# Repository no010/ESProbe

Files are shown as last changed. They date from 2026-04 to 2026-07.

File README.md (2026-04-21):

# ESProbe



ESProbe 是一款基于 **ESP32-C3** 的无线 CMSIS-DAP 调试探针。它通过 WiFi 将 USBIP 协议传输到 PC，使你可以在没有物理 USB 连接的情况下，使用标准调试工具（OpenOCD、Keil、IAR 等）对目标设备进行 SWD 调试。同时内置 UART1 TCP 桥接，方便无线串口调试。

> 本项目固件基于 [wireless-esp8266-dap](https://github.com/windowsair/wireless-esp8266-dap) 移植，适配 ESP-IDF 5.5.x 和 ESP32-C3 硬件平台。

---

## 特性

- **无线 SWD 调试**：通过 WiFi 使用 USBIP 协议，支持 WinUSB 高速传输（512B 包）
- **SPI 硬件加速**：SWD 时钟高达 40MHz（ESP32-C3 SPI2 IOMUX 直接驱动）
- **UART1 TCP 桥接**：独立的 TCP 端口提供无线串口，支持波特率动态切换
- **mDNS 服务**：设备以 `dap.local` 自动发现
- **静态 IP 支持**：默认 `192.168.137.123`，也可使用 DHCP
- **无需 SWO 引脚支持 RTT**：通过标准 SWD 内存读写即可使用 Segger RTT（配合 OpenOCD）
- **低成本硬件**：基于 ESP32-C3-WROOM-02-N4 模组，单面 PCB，立创 EDA 设计

---

## 仓库结构

```
ESProbe/
├── fw/                    # 主固件（ESP-IDF 5.5.x 项目）
│   ├── main/              # 主应用代码
│   ├── components/DAP/    # CMSIS-DAP 核心组件
│   ├── components/USBIP/  # USBIP 协议栈
│   └── build/             # 构建输出
├── hardware/              # 硬件设计文件
│   ├── 3d/                # 外壳 3D 模型
│   ├── *.json             # 立创 EDA 网表
│   └── *.eprj2            # 立创 EDA 项目文件
├── blink/                 # ESP32-C3 LED 示例（验证板子）
├── hello_world/           # ESP32-C3 Hello World 示例
├── bin/                   # OpenOCD 等预编译工具（Windows）
└── README.md
```

---

## 硬件概述

### 主控

- **ESP32-C3-WROOM-02-N4**（乐鑫）
- 160 MHz RISC-V 单核
- 4MB Flash
- 2.4GHz Wi-Fi 802.11 b/g/n + Bluetooth 5 (LE)

### 调试接口（CN1）

10-pin 卧贴连接器（间距 2mm）：

| Pin | 信号 | GPIO | 说明 |
|-----|---|---|---|
| 1 | VCC | — | 3.3V 输出给目标 |
| 2 | GND | — | 地 |
| 3 | UART1 TX  | IO4  | TCP 桥接发送 |
| 4 | UART1 RX  | IO5  | TCP 桥接接收 |
| 5 | SWCLK | IO6  | SPI CLK（IOMUX） |
| 6 | SWDIO | IO7  | SPI MOSI（IOMUX） |
| 7 | nRESET | IO2  | 目标复位（开漏） |
| 8 | nTRST/TDI | IO10 | JTAG 禁用，引脚复用 |
| 9 | GND | — | 地 |
| 10  | GND | — | 地 |

### 状态指示

- **蓝色 LED**（IO0）：WiFi 连接成功后常亮

更多硬件细节参见 [`hardware/README.md`](hardware/README.md)。

---

## 固件概述

### 构建环境

- **ESP-IDF**: v5.5.3
- **目标芯片**: ESP32-C3
- **操作系统**: Windows（Linux/macOS 亦可，需自行配置工具链）

### 快速构建

在 Windows 下使用 ESP-IDF PowerShell：

```powershell
# 打开立创提供的 PowerShell 快捷方式，或手动加载环境
& 'C:\Program Files\PowerShell\7\pwsh.exe' -ExecutionPolicy Bypass -NoProfile -Command "& {. 'C:\Espressif\tools\Microsoft.v5.5.3.PowerShell_profile.ps1'}"

cd fw
idf.py build
idf.py -p COMxx flash monitor
```

详细固件文档参见 [`fw/README.md`](fw/README.md)。

---

## 使用方式

### 1. 连接 WiFi

上电后，设备自动连接 `wifi_configuration.h` 中预配置的 WiFi（默认尝试 `OTA` / `DAP`）。

### 2. 发现设备

- 如果使用静态 IP，直接访问 `192.168.137.123:3240`
- 如果使用 mDNS，通过 `dap.local:3240` 访问

### 3. 在 Windows 上挂载 USBIP

安装 [usbip-win](https://github.com/cezanne/usbip-win) 后：

```powershell
usbip.exe attach -r 192.168.137.123 -b 1-1
```

系统会识别出一个 CMSIS-DAP v2 (WinUSB) 设备，可直接在 Keil、IAR 或 OpenOCD 中使用。

### 4. UART 桥接

使用任意 TCP 客户端连接 `192.168.137.123:1234`：

```powershell
nc 192.168.137.123 1234
```

首次发送的数字字符串会被识别为波特率（如 `115200`），后续数据即为串口透传。

---

## RTT 支持

ESProbe **不需要 SWO 引脚**即可支持 Segger RTT。RTT 通过标准 SWD 内存读写实现：

1. 在目标固件中集成 Segger RTT 代码
2. PC 端启动 OpenOCD，通过 USBIP 连接 ESProbe
3. 使用 OpenOCD RTT 命令读取目标内存缓冲区

```tcl
# OpenOCD 示例
rtt setup 0x20000000 0x1000 "SEGGER RTT"
rtt start
rtt read 0 1024
```

---

## 相关链接

- [ESP32-C3  datasheet](https://documentation.espressif.com/esp32-c3_datasheet_cn.pdf)
- [ESP32-C3 技术参考手册](https://documentation.espressif.com/esp32-c3_technical_reference_manual_cn.pdf)
- [ESP32-C3-WROOM-02-N4 立创商城](https://item.szlcsc.com/datasheet/ESP32-C3-WROOM-02-N4/3281215.html)
- [wireless-esp8266-dap 原项目](https://github.com/windowsair/wireless-esp8266-dap)
- [usbip-win](https://github.com/cezanne/usbip-win)

---

## License

本项目采用 MIT 许可证，详见 [LICENSE](LICENSE)。

固件中的 CMSIS-DAP 代码版权归 ARM Limited 所有，采用 Apache-2.0 许可证。

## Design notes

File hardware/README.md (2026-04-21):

# ESProbe 硬件

ESProbe 采用立创 EDA 设计，单面 PCB，核心为 ESP32-C3-WROOM-02-N4 模组。

## 主要器件

| 位号 | 型号 | 说明 | 供应商 |
|---|---|---|---|
| U1 | ESP32-C3-WROOM-02-N4 | 主控模组，4MB Flash | LCSC C2934560 |
| CN1 | HCZZ0451-8 | 1x8P 卧贴连接器，间距 2mm，调试接口 | LCSC C7433654 |
| USB1 | — | Type-C USB 接口，供电 + UART0 下载 | — |
| D1 | XL-1005UBC | 0402 蓝色 LED，WiFi 状态指示 | LCSC C965795 |
| U3 | — | LDO，3.3V 稳压 | — |
| SW1 | — | 轻触按键，复位/下载 | — |

## 调试连接器（CN1）定义

CN1 为 1x8P（实际引出 10pin，含重复 GND）卧贴连接器，间距 2mm：

```
Pin 1  ── VCC     (3.3V 输出至目标)
Pin 2  ── GND
Pin 3  ── IO4     (UART1 TX)
Pin 4  ── IO5     (UART1 RX)
Pin 5  ── IO6     (SWCLK / FSPICLK)
Pin 6  ── IO7     (SWDIO / FSPID)
Pin 7  ── IO2     (nRESET)
Pin 8  ── IO10    (nTRST / TDI，当前 JTAG 已禁用)
Pin 9  ── GND
Pin 10 ── GND
```

> 注意：Pin 7/8 在物理连接器上为第 7、8 脚，对应原理图中的 IO2 和 IO10。

## 设计文件说明

| 文件 | 格式 | 说明 |
|---|---|---|
| `ESProbe.eprj2` | 立创 EDA 专业版 | 原理图 + PCB 项目文件 |
| `Netlist_Main_2026-04-13.json` | JSON | 立创 EDA 导出的网表 |
| `Netlist_Main_2026-04-13.enet` | 立创网表 | 备用网表格式 |
| `3d/*.stl` | STL | 外壳 3D 打印模型 |
| `ESProbe_backup/` | 立创 EDA | 自动备份历史版本 |

## 硬件特性

- **供电**：5V USB Type-C 输入，板载 LDO 降至 3.3V
- **天线**：ESP32-C3-WROOM-02 板载 PCB 天线，保持 PCB 天线区域净空
- **尺寸**：小型化设计，适配 3D 打印外壳
- **下载**：通过 USB Type-C 直连 UART0，支持一键下载（按住 BOOT + 按 RESET）

## 制板建议

1. 使用立创 EDA 打开 `ESProbe.eprj2`，检查 DRC 后导出 Gerber
2. PCB 天线区域禁止铺铜和放置元件
3. 建议板厚 1.0mm 或 1.2mm，适配 3D 外壳
4. CN1 连接器推荐回流焊，注意卧贴方向与外壳开口对齐

## 外壳

`3d/` 目录包含 STL 格式的上下壳模型，使用 FDM 3D 打印（PLA/PETG 均可）。
安装时先将 PCB 放入下壳，再扣合上壳，CN1 连接器从外壳侧面开口露出。

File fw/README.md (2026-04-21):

# ESProbe 固件

基于 ESP-IDF 5.5.x 的无线 CMSIS-DAP 固件，目标芯片为 ESP32-C3。

## 环境要求

| 项目 | 版本 / 路径 |
|---|---|
| ESP-IDF | v5.5.3 |
| Python | 3.13（由 ESP-IDF 安装程序提供 venv） |
| 芯片目标 | ESP32-C3 |
| 模组 | ESP32-C3-WROOM-02-N4 |

Windows 推荐使用立创/乐鑫提供的 PowerShell 环境快捷方式启动：

```powershell
"C:\Program Files\PowerShell\7\pwsh.exe" -ExecutionPolicy Bypass -NoProfile -Command "& {. 'C:\Espressif\tools\Microsoft.v5.5.3.PowerShell_profile.ps1'}"
```

## 项目结构

```
fw/
├── CMakeLists.txt              # 项目根 CMake，IDF_TARGET=esp32c3
├── sdkconfig.defaults          # 默认 Kconfig（WiFi 缓冲区、TCP 参数等）
├── main/                       # 主应用组件
│   ├── main.c                  # app_main：初始化 WiFi、mDNS、DAP、TCP Server
│   ├── wifi_handle.c           # WiFi STA 模式、静态 IP、事件处理
│   ├── tcp_server.c            # BSD socket TCP 服务器（端口 3240）
│   ├── usbip_server.c          # USBIP Stage1/Stage2 协议处理
│   ├── DAP_handle.c            # DAP 命令环形缓冲 + 工作线程
│   ├── uart_bridge.c           # UART1 <-> TCP 桥接（端口 1234）
│   ├── timer.c                 # DAP 时间戳计数器（ESP32-C3 上 stubbed）
│   ├── dap_configuration.h     # WinUSB、包大小、强制复位等开关
│   └── wifi_configuration.h    # WiFi SSID、静态 IP、功能开关
├── components/
│   ├── DAP/                    # CMSIS-DAP v2.1.0 核心
│   │   ├── config/DAP_config.h # 引脚映射、时钟、能力位
│   │   ├── source/DAP.c        # DAP 命令解析器
│   │   ├── source/SW_DP.c      # SWD 传输（GPIO bit-bang + SPI 高速）
│   │   ├── source/spi_switch.c # SPI2 初始化/去初始化，IOMUX 切换
│   │   ├── source/spi_op.c     # SPI 加速的 SWD 时序操作
│   │   └── source/...          # JTAG_DP.c, SWO.c, swd_host.c 等
│   └── USBIP/                  # USBIP 协议栈 + 描述符
│       ├── usb_descriptor.c    # USB 设备/配置/接口描述符
│       ├── MSOS20_descriptor.c # Microsoft OS 2.0 描述符（WinUSB 免驱）
│       └── usb_handle.c        # USB 控制请求处理
└── managed_components/
    └── espressif__mdns/        # idf.py add-dependency 引入
```

## 构建步骤

```bash
cd fw

# 完整重新构建（推荐首次或修改 sdkconfig 后）
idf.py fullclean
idf.py build

# 烧录并监控串口
idf.py -p COMxx flash monitor
```

烧录偏移：
- Bootloader: `0x0`
- Partition Table: `0x8000`
- App: `0x10000`

## 关键配置

### WiFi 凭证

编辑 `main/wifi_configuration.h`：

```c
static struct {
    const char *ssid;
    const char *password;
} wifi_list[] = {
    {.ssid = "YOUR_SSID", .password = "YOUR_PASSWORD"},
};
```

支持多 AP 轮询，断连后自动切换下一个。

### 静态 IP

同样在 `wifi_configuration.h` 中：

```c
#define USE_STATIC_IP 1
#define DAP_IP_ADDRESS 192, 168, 137, 123
#define DAP_IP_GATEWAY 192, 168, 137, 1
#define DAP_IP_NETMASK 255, 255, 255, 0
```

### 功能开关

| 宏 | 位置 | 默认 | 说明 |
|----|---|---|---|
| `USE_WINUSB` | `dap_configuration.h` | 1 | WinUSB bulk 模式（512B），关闭则回退 HID |
| `USE_SPI_SIO` | `dap_configuration.h` | 1 | MOSI 单线回环，无需物理短接 MISO |
| `USE_UART_BRIDGE` | `wifi_configuration.h` | 1 | UART1 TCP 桥接 |
| `UART_BRIDGE_PORT` | `wifi_configuration.h` | 1234 | 串口桥接 TCP 端口 |
| `USE_MDNS` | `wifi_configuration.h` | 1 | mDNS 服务 `dap.local` |
| `DAP_JTAG` | `DAP_config.h` | 0 | JTAG 已禁用，仅保留 SWD |

## 引脚映射（ESP32-C3）

| 功能 | GPIO | 备注 |
|---|---|---|
| SWCLK | IO6 | FSPICLK，IOMUX 直连，SPI 加速 |
| SWDIO | IO7 | FSPID，IOMUX 直连，SPI 加速 |
| UART1 TX | IO4 | TCP 桥接发送 |
| UART1 RX | IO5 | TCP 桥接接收 |
| nRESET | IO2 | 目标复位，开漏输出 |
| LED | IO0 | WiFi 状态指示灯 |

## 架构说明

### 任务模型

| 任务 | 优先级 | 核心 | 职责 |
|---|---|---|---|
| `tcp_server` | 14 | 0 | 监听 3240 端口，USBIP Stage1/Stage2 协议 |
| `DAP_Task` | 10 | 0 | 从 ringbuffer 取出 DAP 命令并执行 |
| `uart_server` | 2 | — | UART1 <-> TCP 事件处理 |

### USBIP 数据流

1. 主机发送 `OP_REQ_DEVLIST` / `OP_REQ_IMPORT` → 固件回复设备描述符
2. 进入 URB 循环：
   - **EP1 OUT** → DAP 命令 → `dap_dataIN_handle` → 通知 `DAP_Task`
   - **EP1 IN** ← DAP 响应 ← `dap_dataOUT_handle` ← `fast_reply()`
   - **EP0** → USB 控制请求（WinUSB 描述符等）

### SPI 加速

当调试器请求时钟 ≥ 10MHz 时，`DAP_SWJ_Clock()` 调用 `DAP_SPI_Init()`，将 IO6/IO7 切换到 SPI2 IOMUX 功能，以 40MHz APB 时钟硬件驱动 SWD 时序。低速或协议切换时自动回退到 GPIO bit-bang。

## 已知限制

- **SPI 加速未经验证**：`spi_op.c` 在 ESP32-C3 上的时序尚未用逻辑分析仪验证，如调试不稳定可强制使用 GPIO 模式（时钟 < 10MHz）
- **Timer stubbed**：`get_timer_count()` 在 ESP32-C3 上返回 0，DAP 时间戳功能不可用
- **OTA / WebSocket / KCP 未移植**：MVP 版本仅保留无线 DAP + UART 桥接

## 调试串口输出

ESP32-C3 的 UART0（USB-Serial-JTAG）用于固件日志输出，默认波特率 115200。在 `idf.py monitor` 中可直接查看。

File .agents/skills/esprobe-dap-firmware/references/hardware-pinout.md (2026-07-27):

# Hardware Pinout Reference

## ESProbe ESP32-C3 Target Pin Mapping

All debug signals route to the 10-pin ARM Cortex Debug Connector (CN1) unless noted.

| CN1 Pin | Signal | GPIO | IOMUX Function | Direction | Drive | Note |
|---|---|---|---|---|---|---|
| 1 | VCC | — | — | Power out | — | 3.3V to target |
| 2 | SWDIO | 7 | FSPID (FUNC_MTDO_FSPID) | I/O | 5mA | SPI MOSI, SIO mode |
| 3 | UART1 TX  | 4 | GPIO | Output | — | TCP bridge TX |
| 4 | UART1 RX  | 5 | GPIO | Input | — | TCP bridge RX |
| 5 | SWCLK | 6 | FSPICLK (FUNC_MTCK_FSPICLK) | Output | 5mA | SPI CLK |
| 6 | GND | — | — | — | — | |
| 7 | nRESET | 2 | GPIO | OD out | — | Active low, pull-up |
| 8 | nTRST/TDI | 10 | GPIO | OD out | — | JTAG disabled, reused |
| 9 | NC | — | — | — | — | |
| 10 | GND | — | — | — | — | |

## LED

| Function | GPIO | Active | Control Location |
|---|---|---|---|
| WiFi status | 0 | High | `wifi_handle.c` event handler |

## Cross-SoC Pin Comparison

| Signal | ESP8266 | ESP32 | ESP32-C3 | ESP32-S3 |
|---|---|---|---|---|
| SWCLK | 14 | 14 | 6 | 12 |
| SWDIO | 12/13 | 12/13 | 7 | 11 |
| UART1 TX | — | 23 | 4 | — |
| UART1 RX | — | 22 | 5 | — |
| nRESET | 5 | 26 | 2 | 13 |
| nTRST | 0 | 25 | 10 | 14 |
| LED | 15 | 27 | 0 | 4 |

## ESP32-C3 IOMUX Details

When using SPI acceleration, pins must be routed through IOMUX (not GPIO matrix) for full-speed timing:

- **GPIO6 (SWCLK)**: `FUNC_MTCK_FSPICLK` — IO_MUX direct connect for SPI2 clock
- **GPIO7 (SWDIO)**: `FUNC_MTDO_FSPID` — IO_MUX direct connect for SPI2 MOSI

In GPIO fallback mode, pins are switched back via `PIN_FUNC_SELECT(IO_MUX_GPIOx_REG, FUNC_MTCK_GPIO6)` (or equivalent GPIO function).

## Drive Strength

`DAP_SETUP()` sets drive capability to `GPIO_DRIVE_CAP_0` (5mA) for SWCLK and SWDIO on ESP32-C3/S3. Increase if signal integrity is poor at higher frequencies, but watch for overshoot on long traces.

## Adding a New Board Variant

If creating a derivative board with different pins:

1. Update `PIN_*` macros in `components/DAP/config/DAP_config.h`.
2. Ensure the new SWCLK/SWDIO pins support IOMUX SPI2 if SPI acceleration is desired.
3. Update `PORT_JTAG_SETUP()` if the new TDO pin requires special handling (e.g., RTC pin on ESP8266).
4. Verify `DAP_SPI_Init()` uses correct `IO_MUX_GPIOx_REG` and `FUNC_*` constants.

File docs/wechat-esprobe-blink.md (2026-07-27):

# 不要小看 Blink：ESProbe 的第一颗“心跳灯”

做一块调试器，最激动人心的时刻往往不是第一次跑通 OpenOCD，而是板子上那颗小小的 LED 按预期闪起来。

ESProbe 是一个基于 ESP32-C3 的无线 CMSIS-DAP 调试探针。它最终要通过 WiFi 把 USBIP 设备暴露给 PC，让 OpenOCD、Keil、IAR 等工具像使用普通 CMSIS-DAP 一样进行 SWD 调试。但在 USBIP、WinUSB、SWD 时序、UART TCP 桥接这些复杂模块之前，最应该先做的事情其实很朴素：

让板载 LED 闪起来。

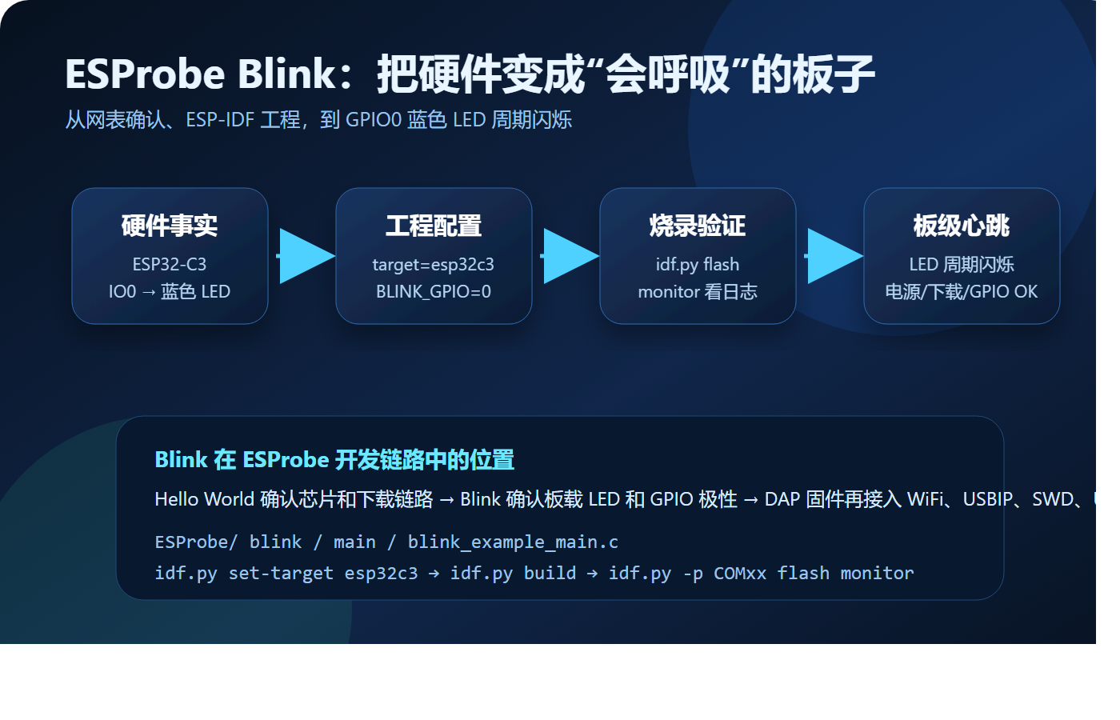
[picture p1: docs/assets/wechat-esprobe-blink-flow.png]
ESProbe Blink 验证流程


## 为什么 Blink 值得单独写一篇

Blink 不是“入门玩具”，而是硬件 Bring-up 的第一道闸门。

对于 ESProbe 这样的板子，Blink 一次性验证了几件基础事实：

| 验证项 | 意义 |
| --- | --- |
| ESP32-C3 能启动 | 电源、Flash、启动配置基本正常 |
| ESP-IDF target 正确 | 工程确实按 `esp32c3` 编译 |
| Type-C 下载链路可用 | 后续固件迭代不会卡在烧录阶段 |
| GPIO 输出可控 | 板载 LED 网络和固件配置对齐 |
| 日志能正常输出 | `idf.py monitor` 能用于后续调试 |

这些事情看起来简单，但如果跳过它们，后面调 WiFi、USBIP 或 SWD 时，一旦出现异常，就很难判断问题来自协议、驱动、网络，还是最底层的硬件没有起来。

## ESProbe 的 LED 接在哪里

ESProbe 的主控是 ESP32-C3-WROOM-02-N4，板载蓝色 LED 连接在 GPIO0 上。这个设计在主固件里也被用作 WiFi 状态指示灯。

需要特别注意的是，很多板载 LED 并不是“GPIO 输出高电平点亮”。ESProbe 的 LED 由 3.3V 侧供电，GPIO0 下拉导通，因此它更接近低电平点亮的连接方式。

在 Blink 示例阶段，我们关心的不是效果多炫，而是先确认固件里的 `BLINK_GPIO` 与硬件事实一致。

## blink 示例项目结构

仓库里的 Blink 工程位于：

```text
blink/
├── CMakeLists.txt
├── sdkconfig.defaults
├── main/
│   ├── blink_example_main.c
│   ├── CMakeLists.txt
│   ├── Kconfig.projbuild
│   └── idf_component.yml
└── managed_components/
```

它来自 ESP-IDF 的标准 blink 示例，但保留在 ESProbe 仓库中后，就不只是示例代码，而是板级验证用例。

顶层 `CMakeLists.txt` 使用 ESP-IDF 标准工程结构，并开启 `MINIMAL_BUILD`：

```cmake
include($ENV{IDF_PATH}/tools/cmake/project.cmake)
idf_build_set_property(MINIMAL_BUILD ON)
project(blink)
```

这让工程只编译必要组件，适合做快速验证。

## 配置 Blink GPIO

Blink 示例通过 Kconfig 暴露了两个关键配置：

```text
CONFIG_BLINK_GPIO
CONFIG_BLINK_PERIOD
```

在 `main/Kconfig.projbuild` 中可以看到默认 GPIO 和闪烁周期配置。对 ESProbe 来说，重点是把 LED 引脚配置到 GPIO0：

```text
BLINK_GPIO=0
BLINK_PERIOD=1000
```

如果 LED 闪烁状态和日志里的 ON/OFF 语义相反，不要急着怀疑芯片坏了。先回到硬件连接，确认 LED 是否为低电平点亮。对嵌入式开发来说，“灯亮了”只是第一步，“灯为什么这样亮”才是真正有价值的结论。

## 主程序做了什么

`blink/main/blink_example_main.c` 的逻辑很清楚：

1. 根据配置选择普通 GPIO LED 或地址灯带。
2. 初始化 GPIO 输出。
3. 在 `while (1)` 中周期性切换状态。
4. 通过 `ESP_LOGI` 打印当前动作。

核心循环可以概括为：

```c
while (1) {
    ESP_LOGI(TAG, "Turning the LED %s!", s_led_state == true ? "ON" : "OFF");
    blink_led();
    s_led_state = !s_led_state;
    vTaskDelay(CONFIG_BLINK_PERIOD / portTICK_PERIOD_MS);
}
```

这段代码的价值不在算法，而在“每一次 GPIO 翻转都有日志对应”。如果串口日志在跑，但 LED 不闪，优先查 GPIO 和硬件连接；如果 LED 闪但没有日志，优先查 monitor、串口号或 USB Serial/JTAG。

## 构建和烧录

在 ESP-IDF 5.5.x PowerShell 环境中执行：

```powershell
cd <你的项目目录>\blink
idf.py set-target esp32c3
idf.py build
idf.py -p COMxx flash monitor
```

正常情况下，日志会周期性出现：

```text
I (xxxx) example: Turning the LED ON!
I (xxxx) example: Turning the LED OFF!
```

同时，ESProbe 板载蓝色 LED 按设定周期闪烁。

## Blink 和 ESProbe 主固件的关系

ESProbe 主固件要做的事情远比 Blink 复杂：

```text
WiFi STA 连接
mDNS 设备发现
TCP 3240 USBIP 服务
WinUSB / CMSIS-DAP v2 描述符
DAP 命令环形缓冲
SWD GPIO / SPI 时序
UART1 TCP 桥接
```

这些模块任何一个出问题，表面现象都可能只是“PC 端连不上”或“调试器不响应”。因此 Blink 的作用就是先给开发者一个底座：板子能启动、能下载、能输出、能控制 GPIO。

有了这颗“心跳灯”，后续调试才有方向感。

## 结语

Blink 是 ESProbe 的第一个可见反馈，也是从硬件设计走向固件系统的分界线。

当蓝色 LED 开始闪烁时，它证明的不只是一个 GPIO，而是整条基础开发链路已经闭合：

```text
硬件网表 → ESP-IDF 工程 → 编译 → 烧录 → 日志 → GPIO 输出
```

下一步，才值得把 WiFi、USBIP 和 CMSIS-DAP 一层层接上去。

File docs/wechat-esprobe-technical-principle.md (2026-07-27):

# ESProbe 技术原理：IDE 以为连着 USB，其实中间跑了一段 WiFi

ESProbe 的目标很直接：把一只基于 ESP32-C3 的小板子变成无线 CMSIS-DAP 调试探针。

但它真正有意思的地方，不是“ESP32-C3 会连 WiFi”，而是它选择了一条非常工程化的路径：

```text
不改 IDE，不改 OpenOCD，不发明私有调试协议。
让电脑仍然看到一个标准 CMSIS-DAP USB 设备。
只是这个 USB 设备，被 USB/IP 搬到了 WiFi 另一端。
```

这篇文章重点拆解 ESProbe 的技术原理，尤其是网络链路，以及它和 IDE、OpenOCD、pyOCD 这些工具之间的架构关系。

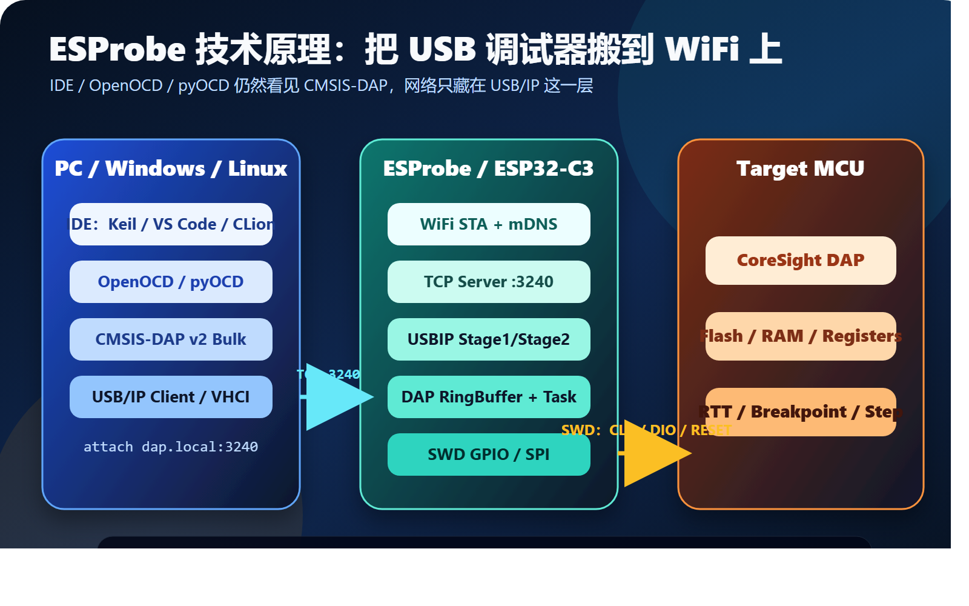
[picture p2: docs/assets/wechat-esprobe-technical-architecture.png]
ESProbe 技术架构图


## 先看一句话架构

ESProbe 可以理解为三层桥接：

| 层级 | ESProbe 做的事 | 上层看到什么 |
| --- | --- | --- |
| 网络层 | ESP32-C3 连接 WiFi，监听 TCP 3240 | 一个 USB/IP 远端设备 |
| USB 层 | 用 USB/IP 模拟 USB 枚举和 URB 传输 | 一个 CMSIS-DAP v2 / WinUSB 设备 |
| 调试层 | 把 DAP 命令转换成 SWD 引脚时序 | 一只普通 CMSIS-DAP 探针 |

也就是说，ESProbe 不是让 OpenOCD 直接通过 TCP 控制 SWD 引脚，而是先让操作系统通过 USB/IP“挂载”一个虚拟 USB 设备。之后 OpenOCD、pyOCD 或 IDE 只需要按普通 CMSIS-DAP 设备来使用它。

## PC 端：IDE 并不知道 WiFi 的存在

在 PC 端，用户通常会使用三类工具：

```text
IDE：Keil、IAR、VS Code、CLion、Eclipse
调试服务：OpenOCD、pyOCD、probe-rs、厂商 GDB Server
底层探针协议：CMSIS-DAP、J-Link、ST-Link、FTDI 等
```

ESProbe 选择 CMSIS-DAP，是因为它是 Arm 生态中比较通用的调试探针协议。Arm 官方对 CMSIS-DAP 的定位，就是在主机调试软件和目标芯片 CoreSight Debug Access Port 之间提供标准化访问。

对 IDE 来说，真正交互的对象往往不是 ESProbe 本身，而是 OpenOCD 或 pyOCD：

```text
IDE / GDB 前端
    ↓
OpenOCD / pyOCD
    ↓
CMSIS-DAP 适配层
    ↓
操作系统中的 USB 设备
```

只要操作系统里出现了一个可用的 CMSIS-DAP v2 设备，上层工具链就可以沿用原来的工作方式。

这正是 ESProbe 的设计重点：网络化发生在 USB/IP 层，而不是强迫每个 IDE 都支持一种新的“WiFi DAP 协议”。

## 网络层：WiFi STA、静态 IP 和 mDNS

ESProbe 固件启动后，首先初始化 NVS、UART 桥、WiFi、DAP 核心和定时器。

在 `app_main()` 中，主要任务包括：

```text
wifi_init()
DAP_Setup()
timer_init()
mdns_setup()
tcp_server_task
DAP_Thread
uart_bridge_task
```

网络部分的核心在 `wifi_handle.c`：

- 使用 ESP32-C3 的 WiFi STA 模式连接路由器或热点。
- 支持多个 SSID 轮询，断线后自动切换。
- 关闭 WiFi 省电模式，降低交互延迟。
- 获取 IP 后点亮 WiFi 状态 LED。
- 默认支持 mDNS，主机名为 `dap.local`。

固件当前的 USB/IP 端口是：

```text
TCP 3240
```

这不是随便选的端口。USB/IP 生态中常用的服务端口就是 3240，因此 Windows 或 Linux 侧的 USB/IP 客户端更容易按标准方式连接。

对用户来说，典型连接目标是：

```text
192.168.137.123:3240
dap.local:3240
```

## TCP Server：先判断你说的是哪种协议

ESProbe 的 `tcp_server_task` 会创建 BSD socket，绑定端口，监听连接。

连接建立后，它先读取 4 字节 header，然后判断对端发来的是什么协议：

| Header 类型 | 含义 | 后续处理 |
| --- | --- | --- |
| USB/IP `OP_REQ_DEVLIST` | 主机请求设备列表 | 返回一个虚拟 USB 设备 |
| USB/IP `OP_REQ_IMPORT` | 主机请求导入设备 | 进入 URB 传输阶段 |
| elaphureLink 标识 | 兼容旧协议入口 | 进入 elaphureLink 处理 |
| 其他 | 未知协议 | 关闭连接 |

ESProbe 主线使用的是 USB/IP。连接断开时，固件会关闭 socket，并通知 DAP 任务重置状态，避免上一次连接残留的 DAP 响应污染下一次会话。

这点很重要。USB 调试链路是有时序和请求-响应关系的，如果网络断开后 ringbuffer 中还有旧响应，下一次 attach 可能会读到错包，导致主机端驱动或调试工具状态错乱。

## USB/IP：把 USB 设备“搬运”到网络上

USB/IP 可以分成两个阶段理解。

第一阶段是发现和导入：

```text
OP_REQ_DEVLIST  →  你有哪些 USB 设备？
OP_REQ_IMPORT   →  我要挂载 busid=1-1 的设备。
```

ESProbe 固件会返回一个设备列表，其中只有一个虚拟设备。它的 busid 是 `1-1`，设备描述符来自固件中的 USB descriptor。

第二阶段是 URB 传输。主机不再问“你有哪些设备”，而是开始像操作 USB 设备一样提交 URB：

| USB/IP Stage2 请求 | ESProbe 行为 |
| --- | --- |
| EP0 控制请求 | 返回设备、配置、字符串、Microsoft OS 2.0 描述符 |
| EP1 OUT | 接收 CMSIS-DAP 命令包 |
| EP1 IN | 返回 CMSIS-DAP 响应包 |
| UNLINK | 取消挂起 URB，清理等待队列 |

这就是 ESProbe 最关键的伪装：它没有真正的 USB 外设控制器连接到 PC，但它通过 USB/IP 回复了足够完整的 USB 行为，让 PC 端认为自己挂载了一个远端 USB 设备。

## 为什么是 CMSIS-DAP v2 / WinUSB

CMSIS-DAP 有两个常见 USB 传输形态：

| 版本 | USB 类型 | 特点 |
| --- | --- | --- |
| CMSIS-DAP v1 | HID | 免驱友好，但包和吞吐受限 |
| CMSIS-DAP v2 | Vendor-specific bulk / WinUSB | 更适合高速传输，pyOCD 和 OpenOCD 都支持 |

ESProbe 默认启用 `USE_WINUSB=1`，并把 DAP packet size 设置为 512 字节。固件还提供 Microsoft OS 2.0 描述符，目的是让 Windows 更容易把接口绑定到 WinUSB。

这对 OpenOCD 和 pyOCD 都很关键。它们并不需要知道 ESProbe 背后是 ESP32-C3，也不需要知道中间是 WiFi。它们只要能通过系统 USB 栈访问到 CMSIS-DAP bulk endpoint，就能发起 DAP 命令。

## DAP 命令如何穿过 ESProbe

一次典型的读内存、写寄存器或下载固件，会被拆成很多 CMSIS-DAP 命令包。

在 ESProbe 内部，数据路径大致是：

```text
USB/IP EP1 OUT
    ↓
handle_dap_data_request()
    ↓
dap_dataIN_handle ringbuffer
    ↓
xTaskNotifyGive(DAP_Task)
    ↓
DAP_ProcessCommand()
    ↓
dap_dataOUT_handle ringbuffer
    ↓
USB/IP EP1 IN fast_reply()
```

这里有两个任务在配合：

| 任务 | 优先级 | 职责 |
| --- | --- | --- |
| `tcp_server_task` | 14 | 处理 TCP、USB/IP、URB 收发 |
| `DAP_Task` | 10 | 执行 CMSIS-DAP 命令，驱动 SWD |

这种设计把网络收发和 DAP 执行拆开：TCP 任务负责尽快接包和回包，DAP 任务负责相对耗时的 SWD 事务。

## 从 CMSIS-DAP 到 SWD 引脚

CMSIS-DAP 命令进入 `DAP_ProcessCommand()` 后，会落到 CMSIS-DAP core 中的具体命令处理逻辑。

对于 ESProbe 当前目标，最重要的是 SWD：

```text
DAP 命令
    ↓
SW_DP.c
    ↓
GPIO bit-bang 或 SPI 加速
    ↓
GPIO6: SWCLK
GPIO7: SWDIO
GPIO2: nRESET
```

ESProbe 固件中 JTAG 当前是关闭的，主路径是 SWD。低速或协议切换阶段使用 GPIO bit-bang；高频数据传输阶段可以尝试通过 ESP32-C3 的 SPI 外设加速 SWD 波形。

从目标芯片角度看，它并不知道调试请求来自 WiFi。它只看到标准的 SWD 时序：SWCLK、SWDIO、nRESET。

## OpenOCD 在这条链路里的位置

OpenOCD 的角色是“调试服务器”和“适配器驱动集合”。

在 ESProbe 场景里，它通常位于 IDE/GDB 和 CMSIS-DAP 设备之间：

```text
GDB / IDE
    ↓ remote target
OpenOCD
    ↓ cmsis-dap adapter
ESProbe 虚拟 USB 设备
    ↓ USB/IP over WiFi
ESProbe 固件
    ↓ SWD
Target MCU
```

OpenOCD 负责理解目标芯片、Flash 算法、断点、寄存器、GDB remote protocol 等；ESProbe 负责把 CMSIS-DAP 命令变成 SWD 电气信号。

这意味着 ESProbe 不需要内置每一种 MCU 的烧录算法。目标芯片差异主要交给 OpenOCD 配置文件处理。

一个典型 OpenOCD 配置思路是：

```tcl
adapter driver cmsis-dap
transport select swd
adapter speed 4000
source [find target/xxx.cfg]
```

如果 Windows 已经通过 USB/IP 把 ESProbe attach 成 CMSIS-DAP v2 设备，OpenOCD 就按普通 CMSIS-DAP 探针使用它。

## pyOCD 在这条链路里的位置

pyOCD 更偏 Python 生态，常用于 Cortex-M 的烧录、调试、自动化测试和脚本化访问。

pyOCD 官方文档把 debug probe 定义为 pyOCD 和 target 之间的接口，并通过 probe driver 插件支持多种探针，其中包括 `cmsisdap`。它也明确区分了 CMSIS-DAP v1 HID 和 v2 bulk，通常会优先使用 v2。

在 ESProbe 场景里，pyOCD 的链路是：

```text
pyocd gdbserver / pyocd flash / Python API
    ↓
cmsisdap probe plugin
    ↓
操作系统 USB 栈中的 CMSIS-DAP v2 设备
    ↓
USB/IP client
    ↓
ESProbe over WiFi
    ↓
SWD target
```

pyOCD 的优势在于脚本化和自动化。如果你希望在 CI、产测脚本或 Python 工具里批量烧录、读取寄存器、做基础连通性测试，pyOCD 会比完整 IDE 更轻量。

## IDE、OpenOCD、pyOCD 和 ESProbe 的边界

可以把它们的职责边界这样记：

| 组件 | 负责什么 | 不负责什么 |
| --- | --- | --- |
| IDE | 用户界面、工程、断点操作 | 不直接处理 WiFi/USBIP |
| OpenOCD | GDB server、目标芯片、Flash、适配器驱动 | 不关心 ESProbe 内部 WiFi 实现 |
| pyOCD | Python 化调试/烧录、CMSIS-DAP probe 访问 | 不负责 ESProbe 的 TCP server |
| USB/IP client | 把远端 USB 设备挂到本机 USB 栈 | 不理解 CMSIS-DAP 语义 |
| ESProbe 固件 | USB/IP server、CMSIS-DAP core、SWD 引脚 | 不内置 IDE 和目标芯片工程逻辑 |

这个分工让系统具有可替换性：

- IDE 可以换，只要它能通过 GDB server 或 CMSIS-DAP 工作。
- OpenOCD 可以换成 pyOCD，只要目标芯片支持。
- Windows USB/IP 客户端可以换，只要它能正确 attach ESProbe。
- ESProbe 固件可以迭代网络和 SWD 性能，而不破坏上层工具链。

## 网络化带来的挑战

无线调试不是把 USB 线剪掉这么简单。ESProbe 需要面对几个网络化后的问题。

第一是时延。USB 调试器原本在本机 USB 总线上，往返延迟很低；WiFi 加 TCP 后，每个请求-响应都会多一层网络时延。因此固件中关闭 WiFi 省电、启用 `TCP_NODELAY`，都是为了减少交互延迟。

第二是队列同步。主机可能预先提交 IN URB，也可能在超时后发送 UNLINK。ESProbe 需要保存待回复的 IN header，并在 DAP 响应准备好后匹配回去；连接断开或取消时还要清理状态。

第三是包大小和吞吐。WinUSB bulk 512 字节包比 HID 更适合传输 DAP 命令，但 WiFi 仍然不是 USB 高速总线。因此 ESProbe 把 USB 速度上报为 Full Speed，并在固件里围绕 512 字节 DAP packet 做处理。

第四是发现和连接体验。静态 IP 简单可靠，mDNS 的 `dap.local` 更方便用户记忆。实际产品化时，还可以继续做配网、设备列表、Web 配置页等体验优化。

## 为什么不直接做一个 OpenOCD TCP Adapter

理论上，ESProbe 可以设计成“OpenOCD 直接连 ESP32-C3 的 TCP 服务，然后发送私有命令”。这样固件可能更简单。

但代价也很明显：

```text
每个工具都要适配私有协议
Windows IDE 很难直接复用
pyOCD 未必能原生支持
用户需要理解更多网络配置
生态兼容性变差
```

USB/IP 的好处是把网络层藏在操作系统 USB 栈下面。只要 attach 成功，后面的软件路径就回到了成熟的 CMSIS-DAP 生态。

ESProbe 的工程取舍是：底层实现更复杂一点，换取上层工具链更少改动。

## 总结

ESProbe 的核心不是“ESP32-C3 + WiFi + SWD”这几个关键词的简单相加，而是一套清晰的分层架构：

```text
IDE / GDB
    ↓
OpenOCD / pyOCD
    ↓
CMSIS-DAP v2
    ↓
USB/IP
    ↓
WiFi TCP 3240
    ↓
ESP32-C3 DAP 固件
    ↓
SWD
    ↓
Target MCU
```

它让网络调试尽量保持“上层无感”：IDE 仍然使用 OpenOCD 或 pyOCD，OpenOCD/pyOCD 仍然使用 CMSIS-DAP，只有 USB 设备本身被 USB/IP 延伸到了 WiFi 另一端。

这就是 ESProbe 最有价值的技术路线：用标准协议做无线化，而不是用私有协议重造整个调试生态。

## 参考资料

- Arm CMSIS-DAP: https://arm-software.github.io/CMSIS_6/main/DAP/index.html
- OpenOCD Debug Adapter Configuration: https://openocd.org/doc-release/html/Debug-Adapter-Configuration.html
- pyOCD Debug Probes: https://pyocd.io/docs/debug_probes.html
- ESProbe 固件：`fw/main/tcp_server.c`、`fw/main/usbip_server.c`、`fw/main/DAP_handle.c`

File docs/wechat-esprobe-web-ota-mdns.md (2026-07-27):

# 给无线调试器装上"大脑"：ESProbe 的一次固件进化

上一篇我们聊了 ESProbe 为什么在 Keil 下用 USBIP 会不稳定，以及 elaphureLink 这条更短的路。这一篇换个视角——不谈协议对抗，谈**产品化**。

一个能跑通 SWD 的 ESP32-C3 只是"能用"。要变成"好用"，还差几样东西：改 WiFi 得重新烧录、升级固件得插线、局域网里两个探针分不清谁是谁、板上那颗灯永远只会"亮"或"不亮"。

这次我们一口气补上了五个特性，让 ESProbe 从"一块能调试的板子"变成"一台有配置界面、能自我升级、可被发现的设备"。

---

## 先看一张改动全景图

```mermaid
flowchart TB
    subgraph 上电启动
    A[app_main] --> B[LED 状态机启动]
    B --> C[USB 序列号<br/>从 MAC 生成]
    C --> D[WiFi 连接]
    D --> E{连上了?}
    E -->|是| F[STA 模式]
    E -->|重试 N 次失败| G[AP fallback 模式]
    end

    F --> H[mDNS 广播<br/>_dap._tcp + _http._tcp]
    G --> H
    H --> I[Web 服务器 :80]
    I --> J[配置门户 /]
    I --> K[状态接口 /status]
    I --> L[OTA 升级 /ota]
```

这五个特性不是孤立的功能点，而是围绕一个核心问题展开：**如何让一台没有屏幕、没有按键阵列的嵌入式设备，具备完整的配置与维护能力？**

---

## 特性一：Web 配置门户——让改 WiFi 不再需要烧录

### 问题的根源

ESProbe 的 WiFi 凭证一直硬编码在 `wifi_configuration.h` 里，改个网络就得重新编译、重新烧录。这在开发阶段能忍，但作为产品是灾难。

上一轮我们已经加了 **NVS 凭证存储**和 **AP fallback 模式**（连不上就自己开热点），但当时留了个尾巴——存储层的 `wifi_config_store_save()` 写好了，却没有任何界面去调用它。用代码评审的话说，这是一段**死代码**。

这一轮就是来补上这最后一块拼图的。

### 方案：AP 模式下的配置网页

当 ESProbe 连不上预设 WiFi、进入 AP fallback 模式（SSID 形如 `ESProbe-A1B2`）后，用手机或电脑连上它，浏览器打开 `192.168.4.1`，就能看到一个配置页：

```
┌─────────────────────────┐
│  ESProbe Config         │
├─────────────────────────┤
│  WiFi                   │
│  [SSID____________]     │
│  [Password________]     │
│  [ Save & Reboot ]      │
├─────────────────────────┤
│  Status  {json...}      │
├─────────────────────────┤
│  Firmware Update (OTA)  │
│  [选择文件] [Upload]     │
└─────────────────────────┘
```

填入新的 SSID/密码，点击保存，固件把凭证写入 NVS 后自动重启，用新配置重连。整个过程不需要电脑上装任何工具，不需要串口，更不需要重新编译。

### 技术细节：为什么用 esp_http_server 而不是自己撸 socket

ESProbe 的 TCP 3240（USBIP/elaphureLink）和 1234（UART 桥）都是手写的 BSD socket 循环。但配置门户我们直接用了 ESP-IDF 自带的 `esp_http_server`：

| 维度 | 手写 socket | esp_http_server |
| --- | --- | --- |
| HTTP 解析 | 自己处理 method/header/body | 内置 |
| 路由 | 自己 if-else | `httpd_register_uri_handler` |
| 分块接收 | 自己管理缓冲 | `httpd_req_recv` |
| 维护成本 | 高 | 低 |

调试器的数据通道追求极致低延迟，值得手写优化；但配置门户是低频操作，稳定和省心比性能重要。**在合适的地方用合适的抽象**，这是工程判断。

表单提交用的是标准 `application/x-www-form-urlencoded`，固件里用 `httpd_query_key_value` 提取字段，再做一次 URL 解码（处理 `%XX` 和 `+`）。这样即使 WiFi 密码里有空格、`&`、中文，也能正确还原。

---

## 特性二：无线 OTA——升级固件不用再插线

### 从"单分区"到"双分区"

要支持在线升级，第一步是改分区表。ESProbe 原本用的是 ESP-IDF 默认的单 App 分区（`singleapp`）——整块 Flash 只有一个固件槽。想 OTA，就必须有第二个槽：写新固件的时候，旧固件还在运行。

我们切换到了 ESP-IDF 内置的 `two_ota` 分区表：

```mermaid
flowchart LR
    subgraph 4MB Flash
    N[nvs] --> O[otadata]
    O --> P[ota_0<br/>1MB app]
    P --> Q[ota_1<br/>1MB app]
    end
```

`otadata` 记录当前该从哪个槽启动。升级时写入空闲槽，成功后把启动指针指向它，重启即生效。如果新固件启动失败，还能回滚——这是双分区最大的价值：**升级失败不变砖**。

> 编译后实测：固件 918KB，单个 app 槽 1MB，剩余 10% 空间。刚好够用，也说明该给未来的功能留意体积了。

### 推还是拉？我们选了"推"

OTA 有两种典型模式：

- **拉（pull）**：设备主动去某个 URL 下载固件（`esp_https_ota`）。适合有固件服务器的量产场景。
- **推（push）**：用户把固件文件直接上传给设备（`esp_ota_ops`）。适合个人开发者、没有服务器的场景。

ESProbe 面向的是 DIY 玩家和小团队，没人会去架一台固件服务器。所以我们选了推模式——网页上选个 `.bin` 文件，点上传，浏览器用 `fetch` 把文件原始字节 POST 到 `/ota`：

```
浏览器 fetch(f) ──raw body──> POST /ota
                                  │
                          esp_ota_begin()
                                  │
                    循环 httpd_req_recv → esp_ota_write()
                                  │
                          esp_ota_end() 校验镜像
                                  │
                    esp_ota_set_boot_partition()
                                  │
                              重启生效
```

这里有个小技巧：没有用 multipart 表单上传（那需要在设备端解析 multipart 边界，很啰嗦），而是让浏览器直接把文件当作请求体裸传。设备端只管一段段收、一段段写 Flash，代码干净很多。

### ⚠️ 一个必须说清楚的坑

分区表从 `singleapp` 变成 `two_ota`，意味着 **Flash 布局彻底变了**。已经烧过旧固件的设备，**第一次必须用 USB 串口全量烧录这个新固件**，之后才能享受 OTA。而且 NVS 分区偏移也变了，旧的 WiFi 凭证会失效，需要重新配置。

这不是 bug，是分区表变更的固有代价。写文档时把它讲明白，比事后被用户追问"为什么 OTA 完就连不上了"要好得多。

---

## 特性三：状态接口——给设备一个"体检报告"

`GET /status` 返回一段 JSON：

```json
{
  "fw_version": "1.0.0",
  "mode": "sta",
  "ip": "192.168.137.123",
  "rssi": -52,
  "uptime_s": 3600,
  "partition": "ota_0",
  "usbip_port": 3240,
  "uart_port": 1234
}
```

别小看这几个字段。对无头设备来说，这是**唯一能一眼看清它状态**的窗口：

- `mode` 告诉你它现在是正常连着路由器（sta）还是掉线开了热点（ap）
- `rssi` 是信号强度——调试老掉线？先看这个是不是太弱
- `partition` 告诉你当前跑在哪个 OTA 槽，升级后可以确认是否切换成功
- `uptime_s` 能帮你发现"是不是偷偷重启过"

配置页顶部会自动 `fetch('/status')` 把它显示出来，也可以被监控脚本、自动化测试直接调用。

---

## 特性四：mDNS 元数据——让设备自我介绍

ESProbe 一直支持 `dap.local` 这个主机名。但这一轮我们让它广播得更"丰富"了——不只是"我在这"，而是"我是谁、我会什么"：

```
_dap._tcp   :3240   TXT: fw=1.0.0
                         device=ESProbe
                         proto=usbip+elaphurelink
                         uart_port=1234
_http._tcp  :80
```

`_dap._tcp` 声明了调试服务和它的能力（同时支持 USBIP 和 elaphureLink），`_http._tcp` 让配置门户能被 Bonjour、Avahi 这类工具自动发现。以后写一个上位机小工具扫一下局域网，就能列出所有 ESProbe 及其固件版本、支持的协议——不用记 IP，不用猜端口。

这就是服务发现的意义：**设备主动说清自己，而不是让用户去猜。**

---

## 特性五：MAC 序列号——让两个探针不再"撞脸"

原来 ESProbe 的 USB 序列号描述符是写死的 `"000000000000"`。一个还好，一旦局域网里挂两个 ESProbe，Windows 设备管理器里就是两个一模一样的 CMSIS-DAP，分不清谁是谁。

修复思路很巧妙：ESP32-C3 的 MAC 地址是 6 字节，转成十六进制正好 12 个字符，而 USB 序列号描述符里预留的正好是 12 个字符的位置（`0x1A` 字节 = 2 字节头 + 12 字符 × 2 字节 UTF-16）。**尺寸严丝合缝**，所以我们只需在启动时用 MAC 填充这个已有的描述符，不用改任何长度、不影响 `sizeof` 计算：

```c
// 6 MAC 字节 → 12 hex 字符，UTF-16LE
for (int i = 0; i < 6; i++) {
    serial[2 + (i*2)*2]   = hex[mac[i] >> 4];   // 高半字节
    serial[2 + (i*2+1)*2] = hex[mac[i] & 0xF];  // 低半字节
}
```

从此每个 ESProbe 都有全局唯一的序列号，比如 `A1B2C3D4E5F6`。多设备环境下终于能对号入座。

---

## 工程哲学：改动虽小，判断不少

回头看这五个特性，真正花心思的不是"怎么写代码"，而是一连串**取舍判断**：

| 决策点 | 选择 | 理由 |
| --- | --- | --- |
| 配置门户用什么 | esp_http_server | 低频操作，稳定 > 性能 |
| OTA 推还是拉 | 推（上传） | 面向个人开发者，无需服务器 |
| OTA 上传格式 | 裸 body 而非 multipart | 设备端解析成本低 |
| 分区表怎么改 | 内置 two_ota | 无需维护自定义 CSV |
| 序列号怎么生成 | 复用 MAC 填充现有描述符 | 尺寸刚好，零副作用 |

还有几个"顺手"的收尾：把上一轮评审指出的"设了没人读"的 `s_ap_mode_active` 变量，做成了 `wifi_is_ap_mode()` 访问器供状态接口调用——一个隐患变成了一个能力。

编译期还踩了两个小坑：`ESP_ERR_WIFI_NOT_CONNECTED` 其实叫 `ESP_ERR_WIFI_NOT_CONNECT`（少个 ED），以及 AP SSID 的 `strncpy` 触发了新版工具链的 `stringop-truncation` 告警——后者用带边界的 `memcpy` + 显式补 `\0` 解决。**新版 ESP-IDF 把更多告警升级成了错误，这其实是好事，逼你把边界情况写清楚。**

---

## 现在的 ESProbe 是什么样

```mermaid
flowchart TB
    U[用户拿到一块新板子] --> P1[上电: LED 慢闪 = 启动中]
    P1 --> P2{能连预设 WiFi?}
    P2 -->|不能| AP[LED 双闪 = AP 模式<br/>连 ESProbe-XXXX]
    AP --> W[浏览器 192.168.4.1<br/>填 WiFi → 保存重启]
    P2 -->|能| STA[LED 常亮 = 已连接]
    W --> STA
    STA --> USE[dap.local 被工具发现<br/>Keil/OpenOCD 开始调试]
    USE --> OTA[有新固件?<br/>网页上传 .bin 秒级升级]
```

从"必须连电脑、装工具、改代码、烧固件"，到"上电、连热点、填 WiFi、开调试"——ESProbe 终于有了一台成熟设备该有的样子。

下一步或许是 TLS 加密、连接认证，或者把 SPI 40MHz 加速用逻辑分析仪验证到底。但那是后话了。

---

## 相关链接

- ESProbe 固件 Web 服务实现：`fw/main/web_server.c`
- WiFi/AP fallback/NVS：`fw/main/wifi_handle.c`、`fw/main/wifi_config_store.c`
- mDNS 元数据：`fw/main/main.c` 的 `mdns_setup()`
- USB 序列号：`fw/components/USBIP/usb_descriptor.c`
- ESP-IDF OTA API：https://docs.espressif.com/projects/esp-idf/zh_CN/latest/esp32c3/api-reference/system/ota.html
- ESP-IDF HTTP Server：https://docs.espressif.com/projects/esp-idf/zh_CN/latest/esp32c3/api-reference/protocols/esp_http_server.html

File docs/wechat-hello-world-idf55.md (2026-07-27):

# 从硬件网表开始：用 ESP-IDF 5.5.x 点亮 ESProbe 的第一个 Hello World

做开源硬件，最容易被忽略的一步不是画板，也不是写代码，而是让硬件设计和固件工程在同一个事实基础上对齐。

ESProbe 是一个基于 ESP32-C3 的无线 CMSIS-DAP 调试探针。最终目标是通过 WiFi 把 USBIP 设备暴露给电脑，让 OpenOCD、Keil、IAR 这类标准调试工具在没有 USB 线直连目标板的情况下，也能通过 SWD 调试目标芯片。

不过在实现无线 DAP、USBIP、UART TCP 桥接之前，第一步应该很克制：先基于硬件网表，确认这块板子的主控、电源、下载、按键和外设引脚，然后用 ESP-IDF 5.5.x 跑通一个最小的 Hello World。

这篇文章记录的就是这个起点。

下面这张图是从 `hardware/Netlist_Main_2026-04-13.json` 提取关键信息后整理出的硬件 pinout 连接图。先看图，再看代码，会更容易理解为什么后面的 target、下载方式、BOOT 按键和 LED 极性要这样处理。

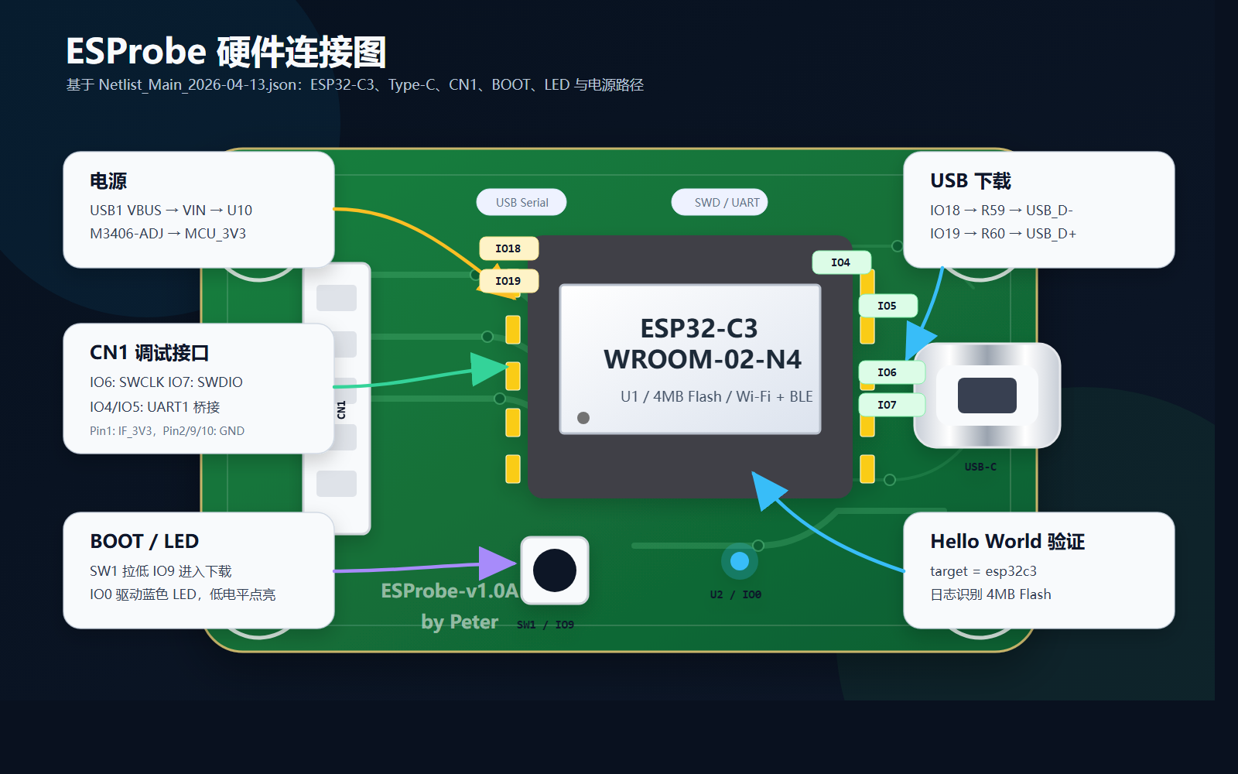
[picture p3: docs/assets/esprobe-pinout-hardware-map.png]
ESProbe 硬件 Pinout 连接图


## 为什么从网表开始

原理图适合人看，网表适合固件开发时做核对。它直接描述“哪个器件的哪个引脚连到了哪个网络”，比凭记忆写 GPIO 更可靠。

ESProbe 仓库里的硬件网表位于：

```text
hardware/Netlist_Main_2026-04-13.json
```

从网表可以确认核心器件是：

```text
U1: ESP32-C3-WROOM-02-N4
厂商: ESPRESSIF 乐鑫
Flash: 4MB
供电: 3V ~ 3.6V
无线: 2.4GHz Wi-Fi + Bluetooth 5
```

也就是说，固件工程的目标芯片应该设置为 `esp32c3`，这会影响编译工具链、启动代码、分区、ROM 接口以及后续 GPIO/SPI/UART 驱动的实现方式。

## 硬件连接先过一遍

先看供电。Type-C 接口 `USB1` 的 VBUS 进入 `VBUS` 网络，经过电源路径后得到 `VIN`，再由 `U10 M3406-ADJ` 转换出 `MCU_3V3`，供给 ESP32-C3 模组。

网表里的关键连接如下：

```text
USB1.A4/A9/B4/B9 -> VBUS
U10.VIN          -> VIN
U10.SW/FB        -> DC-DC 输出反馈网络
U1.3V3           -> MCU_3V3
```

这说明 Hello World 阶段只要 Type-C 供电正常，ESP32-C3 就应该能启动。

再看下载和日志。ESP32-C3-WROOM-02-N4 的原生 USB 连接到了 Type-C：

```text
U1.IO18 -> R59 -> USB_D-
U1.IO19 -> R60 -> USB_D+
USB_D+ / USB_D- -> USB1
```

同时 UART0 也留了测试点：

```text
U1.TXD -> TXD0 -> TP3
U1.RXD -> RXD0 -> TP4
```

这意味着开发时可以优先通过 Type-C 使用 ESP32-C3 的 USB Serial/JTAG 下载和监视；如果需要排查底层启动日志，也可以从 TP3/TP4 接 UART 工具。

启动相关引脚也很关键：

```text
U1.EN  -> R10 10k 上拉到 MCU_3V3，C13 到地
U1.IO9 -> SW1 到 GND
U1.IO8 -> R12 10k 上拉到 MCU_3V3
```

ESP32-C3 进入下载模式通常需要控制启动绑定位。网表显示 IO9 接了按键，按住按键再复位，就可以配合下载流程使用。

最后是板上的指示灯：

```text
U1.IO0 -> U2 蓝色 LED 阴极
U2 阳极 -> R11 1.5k -> MCU_3V3
```

LED 是上拉到 3.3V、由 IO0 下拉点亮的连接方式。也就是说，后续如果写 blink 程序，`gpio_set_level(GPIO_NUM_0, 0)` 才是点亮，`gpio_set_level(GPIO_NUM_0, 1)` 是熄灭。Hello World 本身不需要控制 LED，但这个网表结论会影响后续验证程序。

## 调试接口 CN1

ESProbe 最终要做无线调试探针，所以 CN1 是最重要的外部接口。网表显示：

| CN1 引脚 | 网络 | ESP32-C3 引脚 | 计划用途 |
| --- | --- | --- | --- |
| 1 | IF_3V3 | 由 MCU_3V3 经保护器件输出 | 目标板参考电源 |
| 2 | GND | GND | 地 |
| 3 | IO4/ADC1_CH4/FSPIHD | IO4 | UART1 TX / TCP 串口桥 |
| 4 | IO5/ADC2_CH0/FSPIWP | IO5 | UART1 RX / TCP 串口桥 |
| 5 | IO6/FSPICLK | IO6 | SWCLK |
| 6 | IO7/FSPID | IO7 | SWDIO |
| 7 | IO2/ADC1_CH2/FSPIQ | IO2 | nRESET |
| 8 | IO10/FSPICS0 | IO10 | nTRST/TDI 预留 |
| 9 | GND | GND | 地 |
| 10 | GND | GND | 地 |

这个表会直接进入后续 DAP 固件的 `DAP_config.h`。但在 Hello World 阶段，我们先不碰这些高速和调试相关引脚，只验证最小启动链路。

## 创建 ESP-IDF 5.5.x Hello World 工程

开发环境使用 ESP-IDF 5.5.x。Windows 下可以打开 ESP-IDF PowerShell，或者手动加载环境：

```powershell
& 'C:\Espressif\tools\Microsoft.v5.5.3.PowerShell_profile.ps1'
```

进入项目目录后，创建或使用仓库中的 `hello_world` 工程：

```powershell
cd <你的项目目录>\hello_world
idf.py set-target esp32c3
idf.py build
```

这个工程结构很简单：

```text
hello_world/
├── CMakeLists.txt
└── main/
    ├── CMakeLists.txt
    └── hello_world_main.c
```

顶层 `CMakeLists.txt` 保持 ESP-IDF 工程标准写法：

```cmake
cmake_minimum_required(VERSION 3.16)

include($ENV{IDF_PATH}/tools/cmake/project.cmake)
idf_build_set_property(MINIMAL_BUILD ON)
project(hello_world)
```

`main/CMakeLists.txt` 注册主程序源文件：

```cmake
idf_component_register(SRCS "hello_world_main.c"
                       PRIV_REQUIRES spi_flash
                       INCLUDE_DIRS "")
```

主程序代码如下：

```c
#include <stdio.h>
#include <inttypes.h>
#include "sdkconfig.h"
#include "freertos/FreeRTOS.h"
#include "freertos/task.h"
#include "esp_chip_info.h"
#include "esp_flash.h"
#include "esp_system.h"

void app_main(void)
{
    printf("Hello world!\n");

    esp_chip_info_t chip_info;
    uint32_t flash_size;

    esp_chip_info(&chip_info);

    printf("This is %s chip with %d CPU core(s), %s%s%s%s, ",
           CONFIG_IDF_TARGET,
           chip_info.cores,
           (chip_info.features & CHIP_FEATURE_WIFI_BGN) ? "WiFi/" : "",
           (chip_info.features & CHIP_FEATURE_BT) ? "BT" : "",
           (chip_info.features & CHIP_FEATURE_BLE) ? "BLE" : "",
           (chip_info.features & CHIP_FEATURE_IEEE802154) ? ", 802.15.4 (Zigbee/Thread)" : "");

    unsigned major_rev = chip_info.revision / 100;
    unsigned minor_rev = chip_info.revision % 100;
    printf("silicon revision v%d.%d, ", major_rev, minor_rev);

    if (esp_flash_get_size(NULL, &flash_size) != ESP_OK) {
        printf("Get flash size failed");
        return;
    }

    printf("%" PRIu32 "MB %s flash\n",
           flash_size / (uint32_t)(1024 * 1024),
           (chip_info.features & CHIP_FEATURE_EMB_FLASH) ? "embedded" : "external");

    printf("Minimum free heap size: %" PRIu32 " bytes\n",
           esp_get_minimum_free_heap_size());

    for (int i = 10; i >= 0; i--) {
        printf("Restarting in %d seconds...\n", i);
        vTaskDelay(pdMS_TO_TICKS(1000));
    }

    printf("Restarting now.\n");
    fflush(stdout);
    esp_restart();
}
```

这里有两个细节值得保留。

第一，使用 `CONFIG_IDF_TARGET` 打印目标芯片。因为 ESProbe 的网表已经确认主控是 ESP32-C3，运行结果里应该看到 `esp32c3`。如果这里显示不对，说明工程 target 没有设置正确。

第二，使用 `esp_flash_get_size()` 打印 Flash 容量。ESP32-C3-WROOM-02-N4 是 4MB Flash 模组，运行日志应该能看到 4MB，这可以反向验证当前固件和硬件型号匹配。

## 烧录和串口监视

Type-C 插上 ESProbe 后，查看串口号：

```powershell
idf.py -p COMxx flash monitor
```

如果芯片没有自动进入下载模式，可以按住 BOOT 按键，也就是网表里的 `SW1 -> IO9 -> GND`，再触发复位或重新插入 USB。

正常运行时，日志应包含类似内容：

```text
Hello world!
This is esp32c3 chip with 1 CPU core(s), WiFi/BLE, silicon revision ...
4MB external flash
Minimum free heap size: ...
Restarting in 10 seconds...
```

到这里，第一阶段验证就完成了：

```text
Type-C 供电正常
ESP32-C3 可以启动
ESP-IDF 5.5.x 工程 target 正确
下载链路正常
日志输出正常
Flash 型号与硬件网表一致
```

## 为什么 Hello World 对这个项目重要

ESProbe 后续固件并不是普通的 WiFi 小工具。它要同时处理：

```text
WiFi STA 连接
mDNS 发现
USBIP TCP 服务
CMSIS-DAP 命令处理
SWD GPIO/SPI 时序
UART1 TCP 透传
```

这些模块一上来就全部打开，很难判断问题来自硬件、电源、下载、WiFi 还是协议栈。

Hello World 的价值就是把变量压到最低。只要这个最小程序能稳定启动，就说明板子的基础链路是成立的；后面再逐步加入 LED、WiFi、TCP、DAP，定位问题会清晰很多。

## 下一步

下一篇可以从网表中的 IO0 LED 开始，写一个真正贴合 ESProbe 硬件的 blink 程序：因为 LED 是低电平点亮，代码里要注意电平极性。

再往后，就可以把 CN1 的 IO6/IO7 接入 SWD，验证 GPIO bit-bang，再逐步切到 SPI 加速，为无线 CMSIS-DAP 固件打基础。

开源硬件项目的固件开发，不应该脱离原理图和网表。对 ESProbe 来说，第一个 Hello World 虽然简单，但它把“硬件确实是这块板”和“固件确实跑在这块板上”连接了起来。

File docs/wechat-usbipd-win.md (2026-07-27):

# usbipd-win：为什么 WSL 开发者都应该认识它

很多嵌入式开发者在 Windows 上都会遇到一个尴尬场景：

IDE、串口工具、厂家下载器在 Windows；Linux 编译链、脚本、OpenOCD、容器环境在 WSL；真正的 USB 设备却只能插在一边。

`usbipd-win` 解决的就是这个边界问题。它让插在 Windows 主机上的 USB 设备，通过 USB/IP 共享给 WSL 2、Hyper-V 虚拟机或其他 Linux 客户端。

如果前一篇文章讲的是“Windows 如何挂载远端 USB/IP 设备”，那么 `usbipd-win` 更像反方向：Windows 把本机 USB 设备共享出去。

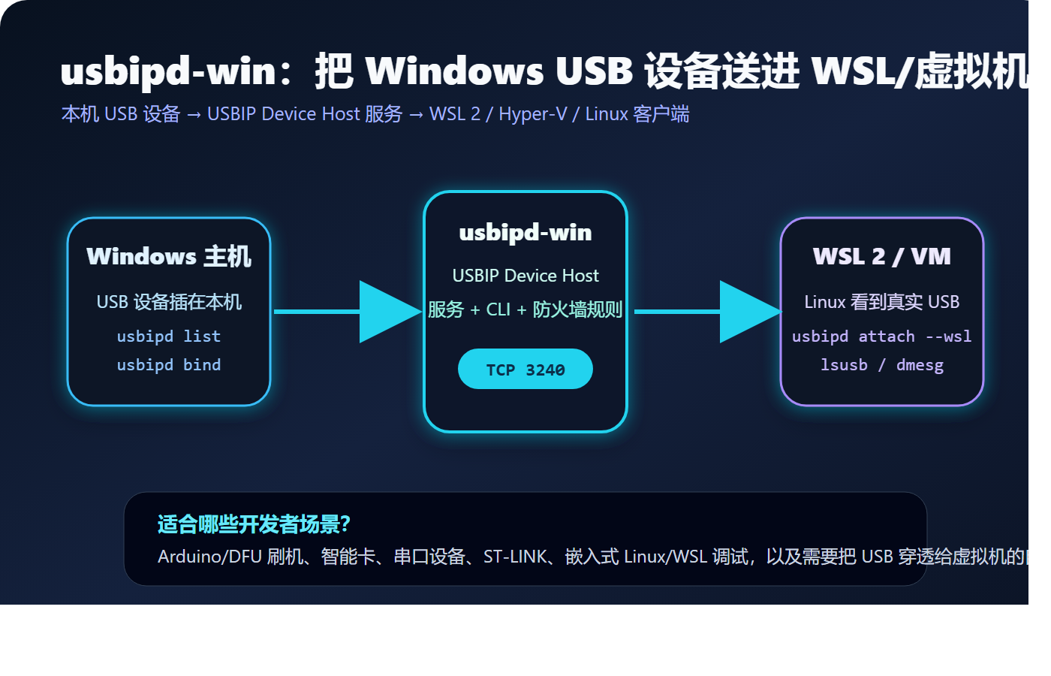
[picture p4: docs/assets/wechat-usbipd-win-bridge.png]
usbipd-win 桥接 Windows 与 WSL


## 它和 usbip-win、usbip-win2 有什么不同

三个名字很像，但定位不同：

| 项目 | 主要方向 | 典型场景 |
| --- | --- | --- |
| usbip-win | Windows USB/IP server + client 早期实现 | 研究完整 USB/IP Windows 支撑 |
| usbip-win2 | Windows USB/IP client | Windows 连接远端 USB/IP server |
| usbipd-win | Windows USB/IP host/server | Windows 把本机 USB 设备共享给 WSL/VM |

也就是说，`usbipd-win` 的核心身份是 Windows 侧的 USBIP Device Host。

它安装后会提供：

- 一个名为 `usbipd` 的 Windows 服务。
- 一个命令行工具 `usbipd`。
- 一个允许本地子网访问服务的防火墙规则。

这让它非常适合 WSL 2：Windows 负责接入真实 USB 设备，WSL 通过 USB/IP 使用这些设备。

## 一个典型工作流

安装可以使用 MSI，也可以通过 Windows Package Manager：

```powershell
winget install --interactive --exact dorssel.usbipd-win
```

然后以管理员 PowerShell 查看设备：

```powershell
usbipd list
```

找到目标设备的 `BUSID` 后，先共享设备：

```powershell
usbipd bind --busid 4-4
```

再用普通权限把设备附加到 WSL：

```powershell
usbipd attach --wsl --busid 4-4
```

进入 WSL 后，可以用 Linux 工具确认：

```bash
lsusb
dmesg | tail
```

这时，设备对 WSL 来说就像插在 Linux 主机上一样。Arduino、DFU、ST-LINK、USB 串口、智能卡读卡器等开发场景，都可以因此进入 WSL 工作流。

## 为什么它对嵌入式开发很有用

WSL 让 Windows 用户拥有了接近 Linux 的开发体验，但 USB 一直是嵌入式开发里的关键短板。

嵌入式开发不是纯软件开发。它需要：

- 通过 USB 串口看日志。
- 通过 DFU 或 Bootloader 下载固件。
- 通过 ST-LINK、J-Link、CMSIS-DAP 调试芯片。
- 通过厂商工具或开源脚本访问 USB 设备。

`usbipd-win` 把这些设备带进 WSL 后，Linux 侧的工具链就能真正参与硬件调试，而不是只能编译代码。

## 和 ESProbe 的关系

ESProbe 的主路径是：

```text
ESProbe 作为 USB/IP server
Windows 作为 USB/IP client
Windows IDE 使用 CMSIS-DAP
```

而 `usbipd-win` 的主路径是：

```text
Windows 本机 USB 设备
usbipd-win 共享
WSL / VM 作为 USB/IP client
Linux 工具使用设备
```

方向相反，但思想一致：都在用 USB/IP 把 USB 设备从物理插拔位置中解放出来。

这也给 ESProbe 项目一个重要参考：好的 USB/IP 工具不只是“协议跑通”，还要让用户能用清晰命令完成发现、共享、附加、验证、释放。

## 使用时要注意什么

第一，USB 设备附加到 WSL 后，Windows 侧通常不能同时使用它。它更像是“借给了 WSL”。

第二，`bind` 通常需要管理员权限，而 `attach --wsl` 可以在普通权限下执行。这种权限分层能降低日常使用成本。

第三，WSL 内核需要支持 USB/IP 和对应设备驱动。如果设备在 `lsusb` 中可见，但应用不可用，就要继续检查 Linux 驱动、udev 权限或内核模块。

第四，USB/IP 经过网络/虚拟化层，不适合所有对时延极端敏感的设备。调试器、串口、刷机工具通常有机会工作良好，但高速等时传输设备要谨慎评估。

## 结语

`usbipd-win` 最有价值的地方，是把 Windows 和 Linux 开发环境之间那条看不见的 USB 边界打通了。

对普通开发者，它让 WSL 真正接近一台可操作硬件的 Linux 主机。

对 ESProbe 这样的项目，它提供了一个成熟参照：当 USB 设备开始在网络中流动，工具链、驱动、权限和用户体验必须一起设计。

## 参考资料

- usbipd-win: https://github.com/dorssel/usbipd-win
- Microsoft Learn：连接 USB 设备到 WSL: https://learn.microsoft.com/zh-cn/windows/wsl/connect-usb
- Windows Command Line Blog：Connecting USB devices to WSL: https://devblogs.microsoft.com/commandline/connecting-usb-devices-to-wsl/

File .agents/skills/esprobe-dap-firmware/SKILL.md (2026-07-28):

---
name: esprobe-dap-firmware
description: ESProbe wireless CMSIS-DAP debug probe firmware for ESP32-C3, based on ESP-IDF 5.5.x. Use when working with the fw/ directory, building/flashing firmware, modifying DAP/SWD/JTAG behavior, adapting GPIO pin mappings, updating WiFi/USBIP stack, porting to new ESP-IDF versions, or debugging SPI acceleration and USBIP protocol issues.
---

# ESProbe DAP Firmware

Wireless CMSIS-DAP debug probe firmware. Exposes a USBIP-over-TCP device on the network so hosts can use standard debug tools (OpenOCD, Keil, etc.) without a physical USB connection.

## Project Layout

```
fw/
├── CMakeLists.txt              # Project root, IDF_TARGET=esp32c3
├── sdkconfig.defaults          # Default Kconfig for ESP32-C3
├── main/                       # Main application component
│   ├── main.c                  # app_main: WiFi, mDNS, DAP, TCP server, web server tasks
│   ├── wifi_handle.c           # STA mode, AP fallback, static IP, event handlers
│   ├── wifi_config_store.c     # NVS persistence for WiFi credentials
│   ├── web_server.c            # HTTP config portal + status + OTA + web terminal (port 80)
│   ├── access_control.c        # Optional PIN gate for debug ports (NVS + IP sessions)
│   ├── tcp_server.c            # BSD socket listener on port 3240
│   ├── usbip_server.c          # USBIP stage1/2 protocol handler
│   ├── DAP_handle.c            # DAP command ringbuffer + worker thread
│   ├── uart_bridge.c           # Optional UART<->TCP bridge
│   ├── led_status.c            # Status LED patterns
│   ├── button_handle.c         # Boot button handling
│   ├── timer.c                 # DAP timestamp via esp_timer (1 MHz, TIMESTAMP_CLOCK)
│   ├── dap_configuration.h     # WinUSB, packet size, reset options
│   └── wifi_configuration.h    # SSID list, static IP, feature toggles
├── components/
│   ├── DAP/                    # CMSIS-DAP core + SPI GPIO switch
│   │   ├── config/DAP_config.h # Pin mapping, clock, capabilities
│   │   ├── include/gpio_op.h   # SoC-specific fast GPIO macros
│   │   ├── include/gpio_common.h # SoC header includes
│   │   ├── source/spi_switch.c # SPI init/deinit for SWD acceleration
│   │   └── source/...          # DAP.c, SW_DP.c, JTAG_DP.c, etc.
│   ├── USBIP/                  # USB descriptor + MSOS20 descriptors
│   └── elaphureLink/           # elaphureLink proxy protocol (handshake + DAP framing over TCP 3240)
└── managed_components/
    └── espressif__mdns/        # Component manager dependency
```

## Build & Flash

Prerequisites (Windows):
- ESP-IDF v5.5.x at `C:\esp\v5.5.4\esp-idf` (currently v5.5.4)
- Launch IDF PowerShell: `& . 'C:\Espressif\tools\Microsoft.v5.5.4.PowerShell_profile.ps1'`
- Target: ESP32-C3-WROOM-02-N4

```powershell
cd fw
idf.py build
idf.py -p COMxx flash monitor
```

Project-owned verification (build + binary check, auto-loads IDF env):

```powershell
pwsh -File fw/scripts/verify_build.ps1
```

Run it after any firmware change; exit code 0 confirms the build produced `fw/build/esprobe_dap.bin`.

Partition offsets: bootloader 0x0, partition table 0x8000, app 0x10000.

## Key Configuration

### Hardware Pin Mapping (ESP32-C3)

Edit `fw/components/DAP/config/DAP_config.h` for pin changes:

| Signal | GPIO | Note |
|---|---|---|
| SWCLK | 6 | SPI CLK (IOMUX direct) |
| SWDIO | 7 | SPI MOSI (SIO mode) |
| UART1 TX | 4 | TCP bridge TX |
| UART1 RX | 5 | TCP bridge RX |
| nRESET | 2 | Open-drain, pull-up |
| nTRST/TDI  | 10 | JTAG disabled, pin reused  |
| LED | 0 | WiFi status |

CPU_CLOCK is 160 MHz. Drive capability set to 5mA for SWCLK/SWDIO.

### Feature Toggles

In `fw/main/dap_configuration.h` and `fw/main/wifi_configuration.h`:

| Macro | Default | Purpose |
|---|---|---|
| `USE_WINUSB` | 1 | WinUSB bulk mode (512B packets)  |
| `USE_SPI_SIO` | 1 | MOSI only, no MISO loopback |
| `USE_UART_BRIDGE`  | 1 | UART1 TCP bridge on port 1234 |
| `USE_STATIC_IP` | 注释掉（DHCP） | 取消注释后启用 192.168.137.123 |
| `USE_MDNS` | 1 | dap.local |
| `USE_OTA` | 0 | 宏未启用；web_server.c 仍提供 /ota 端点（见 Known Issues） |
| `USE_KCP` | 0 | Experimental, not supported |
| `DAP_JTAG` | 0 | JTAG disabled, SWD only |

### SDKConfig Critical Values

`fw/sdkconfig.defaults` must maintain:
- `CONFIG_ESP_WIFI_STATIC_RX_BUFFER_NUM=32` (must be >= RX_BA_WIN/2)
- `CONFIG_ESP_WIFI_RX_BA_WIN=32`
- `CONFIG_ESP_WIFI_TX_BA_WIN=32`
- `CONFIG_UART_ISR_IN_IRAM=y`

## Common Modifications

### Changing WiFi Credentials
Edit `wifi_list[]` in `fw/main/wifi_configuration.h`. The firmware auto-rotates through entries on disconnect.

### Changing Static IP
Default is DHCP (`USE_STATIC_IP` is commented out in `wifi_configuration.h`). Uncomment it to use the static address baked into `wifi_handle.c` (lines with `ESP_IP4TOADDR`).

### Adding a New ESP Target (e.g., ESP32-C6)
1. Add `CONFIG_IDF_TARGET_ESP32C6` blocks in:
   - `DAP_config.h` (pins, CPU_CLOCK, PORT_JTAG_SETUP, PORT_OFF, nRESET_OUT)
   - `gpio_op.h` (GPIO_FUNCTION_SET, GPIO_SET_DIRECTION_NORMAL_OUT, level macros)
   - `gpio_common.h` (SoC headers)
   - `spi_switch.c` (DAP_SPI_Init, DAP_SPI_Deinit, DAP_SPI_Acquire/Release)
   - `wifi_handle.c` (PIN_LED_WIFI_STATUS)
   - `uart_bridge.c` (UART port/pins)
2. Use `gpio_ll_*` HAL for RISC-V targets (ESP32-C3/C6/H2 style).
3. Verify SPI register struct names in the new SoC TRM; Espressif changes field names between chips.

### Disabling SPI Acceleration (fallback to bit-bang)
In `dap_configuration.h`, there is no single toggle. SPI mode is selected at runtime by `DAP_SPI_Init()` / `DAP_SPI_Deinit()` in `spi_switch.c`. To force GPIO mode, stub out `DAP_SPI_Init()` to only configure GPIO outputs, and ensure `DAP_SPI_Deinit()` is always called before SWD transfers.

### Porting to Newer ESP-IDF
See [references/idf-migration.md](references/idf-migration.md) for the API migration checklist.

## Architecture Notes

### Tasking Model
- `tcp_server_task` (priority 14, core 0): Accepts USBIP connections, parses stage1 headers, then calls `usbip_worker()` which blocks in `usbip_urb_process()`.
- `DAP_Thread` (priority 10, core 0): Processes DAP commands from a ringbuffer. Notified by `xTaskNotifyGive()` from TCP path.
- `uart_bridge_task` (priority 2): Optional UART<->TCP bridge.

### USBIP Protocol Flow
1. Host sends `OP_REQ_DEVLIST` or `OP_REQ_IMPORT` (stage1).
2. Server replies with device descriptor, then enters URB loop (stage2).
3. URBs on EP1 OUT contain DAP command data → pushed to `dap_dataIN_handle` ringbuffer.
4. URBs on EP1 IN request DAP response → `fast_reply()` pulls from `dap_dataOUT_handle`.
5. EP0 handles USB control requests (WinUSB descriptor, MSOS20, etc.).

### SPI vs GPIO Mode for SWD
- `PORT_SWD_SETUP()` calls `DAP_SPI_Deinit()` to ensure pins are in GPIO mode for initial pin state reads.
- When `DAP_SWJ_Clock` sets a high frequency, `DAP_SPI_Init()` switches pins to SPI function for hardware-accelerated transfer.
- `DAP_SPI_Acquire()` / `DAP_SPI_Release()` manage SPI clock pin muxing during transactions.

## Known Issues & Constraints

- **SPI acceleration unverified on ESP32-C3**: `spi_switch.c` compiles but needs logic-analyzer/scope validation against a real target. Fallback GPIO mode works.
- **Timer implemented on C3**: `get_timer_count()` returns `esp_timer_get_time()` microseconds (`TIMESTAMP_CLOCK 1MHz`); wraps every ~71 min, still stubbed to 0 only on targets without esp_timer wiring.
- **JTAG disabled**: `DAP_JTAG 0` in `DAP_config.h`. Only SWD is supported.
- **elaphureLink proxy present**: `components/elaphureLink` implements the elaphureLink handshake/DAP framing and is wired into `tcp_server.c` (mDNS advertises `usbip+elaphurelink`). `DAP_vendor.c` still stubs `ID_DAP_Vendor8`; WebSocket and KCP remain absent.
- **Web OTA functional**: `web_server.c` serves a config portal with `POST /ota`; `sdkconfig.defaults` sets `CONFIG_PARTITION_TABLE_TWO_OTA=y` (otadata + factory + ota_0 + ota_1). If OTA reports "No OTA partition" at runtime, the local `sdkconfig` was generated before this default existed — delete `fw/sdkconfig` and rebuild to regenerate it from defaults.
- **Optional PIN gate**: when a PIN is set via the web portal (`POST /pin`), TCP 3240/1234 only accept clients unlocked through `POST /unlock` (per-IP, until reboot). No PIN = fully open (backward compatible). Plain-HTTP PIN, LAN deterrent only.
- **Web serial terminal**: `GET /terminal` + WebSocket `/ws/uart` (needs `CONFIG_HTTPD_WS_SUPPORT=y`). Single WS client; while connected the TCP 1234 bridge pauses UART RX forwarding (shared-claim in `uart_bridge.c`).
- **CSR GPIO unavailable**: ESP32-C3 CSR instructions (`RV_SET_CSR`) removed; toolchain incompatibility in IDF 5.5.x. Use `gpio_ll_*` instead.
- **Static IP hardcoded**: `wifi_handle.c` embeds IP directly; `wifi_configuration.h` macros not fully used there.

## References

- **Hardware pinout & SoC differences**: [references/hardware-pinout.md](references/hardware-pinout.md)
- **ESP-IDF migration guide (4.x → 5.5.x)**: [references/idf-migration.md](references/idf-migration.md)
- **USBIP protocol & WinUSB descriptors**: [references/usbip-protocol.md](references/usbip-protocol.md)
- **CMSIS-DAP core & SPI acceleration**: [references/dap-core.md](references/dap-core.md)

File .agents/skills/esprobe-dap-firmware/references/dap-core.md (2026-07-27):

# CMSIS-DAP Core & SPI Acceleration Reference

## Core Files

| File | Purpose |
|---|---|
| `components/DAP/source/DAP.c` | CMSIS-DAP command parser and state machine |
| `components/DAP/source/SW_DP.c` | SWD transfer protocol (bit-bang + SPI fast)  |
| `components/DAP/source/JTAG_DP.c` | JTAG scan chain handling |
| `components/DAP/source/DAP_vendor.c` | Vendor command hooks (elaphureLink stubbed) |
| `components/DAP/source/spi_op.c` | SPI-accelerated SWD transfer routines |
| `components/DAP/source/spi_switch.c` | SPI init/deinit and pin mux switching |
| `components/DAP/source/swd_host.c` | High-level SWD host (reset, connect) |

## GPIO Abstraction Layer

`gpio_op.h` provides `__STATIC_INLINE` macros for fast pin access. On ESP32-C3:

```c
GPIO_SET_LEVEL_HIGH(pin)   → gpio_ll_set_level(&GPIO, pin, 1)
GPIO_SET_LEVEL_LOW(pin)    → gpio_ll_set_level(&GPIO, pin, 0)
GPIO_GET_LEVEL(pin)        → gpio_ll_get_level(&GPIO, pin)
SWDIO_OUT_ENABLE()         → gpio_ll_output_enable(&GPIO, PIN_SWDIO_MOSI)
SWDIO_OUT_DISABLE()        → gpio_ll_output_disable(&GPIO, PIN_SWDIO_MOSI)
```

These are used by `SW_DP.c` for software bit-banging and by `DAP_config.h` for JTAG pin setup.

## SPI Acceleration Architecture

### When SPI Mode is Used

`DAP_SPI_Init()` is called when `DAP_SWJ_Clock` sets a frequency that benefits from hardware SPI (typically > 1 MHz). The firmware switches SWCLK/SWDIO pins from GPIO to SPI2 peripheral.

### SPI Configuration (ESP32-C3)

- **Peripheral**: `GPSPI2` (SPI2)
- **Clock**: 40 MHz (APB / 2)
- **Mode**: CPOL=1, CPHA=0 (idle high, sample on rising edge)
- **Bit order**: LSB first (matches SWD protocol)
- **Duplex**: Half-duplex (`doutdin = false`)
- **Buffer**: 64-byte hardware FIFO, no DMA

### Init Sequence (`DAP_SPI_Init`)

1. Enable SPI2 clock and clear reset.
2. Clear any previous GPIO output levels on SWCLK/SWDIO.
3. Route GPIO6/7 to SPI via IOMUX (`PIN_FUNC_SELECT(IO_MUX_GPIO6_REG, FUNC_MTCK_FSPICLK)`).
4. Configure SPI registers (master mode, no CS, clock divider, polarity, bit order).
5. Enable SPI clock gating (`clk_en`, `mst_clk_active`, `mst_clk_sel`).

### Deinit Sequence (`DAP_SPI_Deinit`)

1. Switch pins back to GPIO function.
2. Route pin output through `CPU_GPIO_OUTx_IDX` (GPIO matrix) instead of SPI peripheral.
3. Re-enable GPIO output and input on SWCLK and SWDIO.

### Acquire / Release

During a multi-byte SPI transaction, `DAP_SPI_Acquire()` keeps the clock pin muxed to SPI. `DAP_SPI_Release()` temporarily returns it to GPIO if the transfer routine needs to bit-bang a turnaround cycle.

## SWD Bit-Bang vs SPI Decision

`SW_DP.c` decides at runtime based on clock frequency:
- Low frequency or protocol turnaround phases → GPIO bit-bang via `PIN_SWCLK_TCK_SET/CLR` and `PIN_SWDIO_OUT/IN`.
- High frequency bulk data → `spi_op.c` routines that blast bytes through SPI FIFO.

## Adding SPI Support for a New SoC

1. Define `DAP_SPI` macro (e.g., `SPI2`, `GPSPI2`).
2. Implement `DAP_SPI_Init()`:
   - Enable peripheral clock.
   - Map SWCLK/SWDIO to correct IOMUX functions.
   - Set clock divider for 40 MHz (or target max).
   - Configure CPOL=1, CPHA=0, LSB first.
3. Implement `DAP_SPI_Deinit()`:
   - Return pins to GPIO mode.
   - Ensure output enable and input enable are restored.
4. Implement `DAP_SPI_Acquire()` / `DAP_SPI_Release()` if needed for pin mux toggling.
5. Verify register field names in `spi_struct.h` — they vary significantly between ESP32, ESP32-C3, ESP32-S3, etc.

## JTAG Mode

JTAG is **disabled** (`DAP_JTAG 0`). The project only supports SWD. JTAG-related pins (TDO, TDI, nTRST) are either reused for other functions or left undefined in the DAP protocol layer.

## RTT Support

**RTT (Real-Time Transfer) does not require SWO or extra pins.** It works over standard SWD memory read/write:
1. Target runs RTT code (Segger RTT or open-source alternative)
2. PC connects via USBIP to ESProbe
3. Use **OpenOCD** with its `rtt` command to poll target memory and forward RTT data

No firmware changes are needed for basic RTT support.

## Known Limitations

- **ESP32-C3 SPI untested**: The `spi_op.c` fast path may have timing issues with turnaround cycles. If debugging fails at high SWD frequencies, force GPIO mode by ensuring `DAP_SPI_Init()` is never called (or stub it).
- **No SWO**: `SWO_FUNCTION_ENABLE == 0`. UART SWO and Manchester SWO are not compiled in.
- **No adaptive clocking**: `PIN_SWCLK_TCK_IN()` returns 0; the firmware does not support wait-state detection from the target.

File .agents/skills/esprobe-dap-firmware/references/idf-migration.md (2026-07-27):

# ESP-IDF Migration Reference

This project was ported from ESP-IDF 4.x patterns to ESP-IDF 5.5.3. Use this when upgrading to future IDF versions or adding new SoC support.

## Critical API Changes (4.x → 5.5.x)

### Network Stack

| Old API (4.x) | New API (5.5.x) | File |
|---|---|---|
| `tcpip_adapter_init()` | `esp_netif_init()` | `wifi_handle.c` |
| `tcpip_adapter_create_default…`| `esp_netif_create_default_wifi_sta()` | `wifi_handle.c` |
| `tcpip_adapter_dhcpc_stop()` | `esp_netif_dhcpc_stop()` | `wifi_handle.c` |
| `tcpip_adapter_set_ip_info()`  | `esp_netif_set_ip_info()` | `wifi_handle.c` |
| `esp_event_loop_init()` | `esp_event_loop_create_default()` | `wifi_handle.c` |
| `ESP_IF_WIFI_STA` | `WIFI_IF_STA` | `wifi_handle.c` |
| `IP4_ADDR(&ip, a,b,c,d)` | `ip.addr = ESP_IP4TOADDR(a,b,c,d)` | `wifi_handle.c` |
| `system_event_t` | `esp_event_base_t` + `int32_t event_id` | `wifi_handle.c` |

### GPIO HAL

| Old Pattern | New Pattern (IDF 5.5.x) | Notes |
|---|---|---|
| `GPIO.enable_w1ts = …` | `gpio_ll_output_enable(&GPIO, pin)` | RISC-V safe |
| `GPIO.enable_w1tc = …` | `gpio_ll_output_disable(&GPIO, pin)` | RISC-V safe |
| `GPIO.out_w1ts = …` | `gpio_ll_set_level(&GPIO, pin, 1)` | Unified |
| `GPIO.out_w1tc = …` | `gpio_ll_set_level(&GPIO, pin, 0)` | Unified |
| `GPIO.in >> pin` | `gpio_ll_get_level(&GPIO, pin)` | Unified |
| `GPIO.pin[x].pad_driver = 0` | `gpio_ll_od_disable(&GPIO, pin)` | ESP32-C3/S3 |
| `GPIO.pin[x].pad_driver = 1` | `gpio_ll_od_enable(&GPIO, pin)` | ESP32-C3/S3 |
| `PIN_INPUT_ENABLE()` | `gpio_ll_input_enable(&GPIO, pin)` | ESP32-C3/S3 |

### SoC Headers

ESP-IDF 5.5 restructured register headers:

| Old Path (IDF 4.x) | New Path (IDF 5.5.x) |
|---|---|
| `soc/esp32c3/include/soc/gpio_struct.h` | `soc/gpio_struct.h` (C3 uses flat path) |
| `soc/esp32c3/include/soc/dport_access.h` | `soc/dport_access.h` |
| `soc/esp32c3/include/soc/periph_defs.h` | `soc/periph_defs.h` |
| `hal/esp32c3/include/hal/gpio_ll.h` | `hal/gpio_ll.h` |

Note: ESP32 and ESP32-S3 still use `soc/esp32s3/include/soc/gpio_struct.h` style paths.

### Register Struct Field Names

Espressif changed field names in `gpio_struct.h` for IDF 5.5:

| Old Name | New Name | Context |
|---|---|---|
| `GPIO.func_out_sel_cfg[N].func_sel` | `GPIO.func_out_sel_cfg[N].out_sel` | `spi_switch.c` |
| `GPIO.func_in_sel_cfg[N].func_sel` | `GPIO.func_in_sel_cfg[N].in_sel` | `spi_switch.c` |

Verify with `soc/gpio_struct.h` for your target if build fails with "has no member named".

### Toolchain Incompatibilities

**CSR GPIO (ESP32-C3)**: The `RV_SET_CSR(CSR_GPIO_OUT_USER, …)` inline assembly used in older versions is **not supported** by riscv32-esp-elf-gcc 14.2 in IDF 5.5.3. Replaced with `gpio_ll_set_level()` and `gpio_ll_get_level()`.

## Component Manager

Dependencies are managed via `idf.py add-dependency`:
```powershell
idf.py add-dependency espressif/mdns
```
This creates `main/idf_component.yml` and downloads to `managed_components/`.

## CMake Modernization

All components use `idf_component_register()`:

```cmake
idf_component_register(
    SRCS "source1.c" "source2.c"
    INCLUDE_DIRS "include" "config"
    REQUIRES "driver" "freertos"
    PRIV_REQUIRES "main"
)
```

Avoid legacy `register_component()` or manual `add_library()` patterns.

## sdkconfig.defaults Rules

When adding new WiFi features, maintain this invariant:
```
CONFIG_ESP_WIFI_STATIC_RX_BUFFER_NUM >= CONFIG_ESP_WIFI_RX_BA_WIN / 2
```
Current defaults set both to 32.

## Debugging Build Failures

1. `fatal error: soc/xxx: No such file` → Check `gpio_common.h` include paths for your target.
2. `error: 'func_sel' has no member named` → Update to new field name (`out_sel`/`in_sel`).
3. `implicit declaration of function 'tcpip_adapter_...'` → You are using obsolete network API; migrate to `esp_netif_*`.
4. `undefined reference to 'gpio_matrix_out'` → Use `gpio_ll_iomux_out` / `gpio_ll_iomux_in` or `PIN_FUNC_SELECT` instead.

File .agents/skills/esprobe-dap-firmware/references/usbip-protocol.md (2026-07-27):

# USBIP Protocol Reference

## Overview

The firmware emulates a USB device over TCP using the Linux USB/IP protocol. The host runs a USBIP client (e.g., `usbip` on Linux, or usbip-win on Windows) that attaches to `esprobe_ip:3240`.

## Connection Lifecycle

### Stage 1: Discovery / Attach

The TCP server (`tcp_server.c`) accepts a connection, reads a 4-byte header, then branches:

| Header (ntohl) | Command | Handler |
|---|---|---|
| `0x8005` | `OP_REQ_DEVLIST` | `attach()` → device list |
| `0x8003` | `OP_REQ_IMPORT` | `attach()` → single device info |

Both replies include:
- `usbip_stage1_header` (version 273, status 0)
- `usbip_stage1_response_devlist` (list_size = 1)
- `usbip_stage1_usb_device` (vendor/product IDs from descriptor)
- `usbip_stage1_usb_interface` (class/subclass/protocol)

### Stage 2: URB Emulation

After attach, `usbip_urb_process()` loops reading 48-byte USBIP stage2 headers from the socket.

#### URB Types

| Command | Direction | EP  | Handler |
|---|---|-----|---|
| `USBIP_STAGE2_REQ_SUBMIT` | OUT | 1 | `handle_dap_data_request()` |
| `USBIP_STAGE2_REQ_SUBMIT` | IN | 1 | `fast_reply()` |
| `USBIP_STAGE2_REQ_SUBMIT` | — | 0 | `handleUSBControlRequest()` |
| `USBIP_STAGE2_REQ_UNLINK` | — | — | `handle_unlink()` |

#### Data Flow (EP1 OUT → IN)

1. Host sends DAP command payload in `USBIP_CMD_SUBMIT` OUT.
2. `handle_dap_data_request()` copies payload to `dap_dataIN_handle` ringbuffer.
3. `xTaskNotifyGive(kDAPTaskHandle)` wakes `DAP_Thread`.
4. `DAP_Thread` calls `DAP_ProcessCommand()`, writes response to `dap_dataOUT_handle`.
5. Host sends `USBIP_CMD_SUBMIT` IN (ep=1, dir=IN).
6. `fast_reply()` pulls response from `dap_dataOUT_handle` and sends `USBIP_RET_SUBMIT`.

#### Unlink Handling

`USBIP_CMD_UNLINK` aborts pending URBs. The firmware drains stale responses from `dap_dataOUT_handle` to prevent out-of-sync replies that crash the host driver.

## USB Descriptors

Descriptors are hardcoded in `components/USBIP/`:

- `usb_descriptor.c` — Standard USB device/configuration/interface/endpoint descriptors
- `MSOS20_descriptor.c` — Microsoft OS 2.0 descriptor for WinUSB auto-binding

### WinUSB Mode

When `USE_WINUSB == 1`:
- Packet size = 512 bytes (`DAP_PACKET_SIZE`)
- MSOS20 descriptor tells Windows to bind the interface to WinUSB.sys without an INF file
- USB endpoint 1 is used for bulk transfer (instead of HID interrupt)

### Control Requests (EP0)

`handleUSBControlRequest()` in `components/USBIP/usb_handle.c` handles:
- `GET_DESCRIPTOR` (device, config, string, MSOS20)
- `SET_CONFIGURATION`
- Vendor-specific MSOS20 queries

## Adding New Endpoints

Current descriptor defines EP1 (DAP data) and reserves EP3 (SWO, not implemented). To add a new endpoint:

1. Update endpoint descriptor in `usb_descriptor.c`.
2. Add EP number/direction handling in `usbip_urb_process()`.
3. Ensure `send_stage2_submit()` / `send_stage2_submit_data()` populate `data_length` correctly.

## Debugging USBIP Issues

- **"Unknown protocol"** in logs → Host sent unexpected stage1 command; check header bytes with Wireshark.
- **Host driver panic after reconnect** → Likely stale DAP response in ringbuffer; verify `handle_dap_unlink()` drains `dap_dataOUT_handle`.
- **Zero-length URB spam** → Normal for IN endpoints when no data is ready; `fast_reply()` sends empty `RET_SUBMIT`.

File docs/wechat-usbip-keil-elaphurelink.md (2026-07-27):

# 设备管理器绿灯亮了，Keil 却装看不见：USBIP 无线调试到底卡在哪一层？

你做过无线调试器，大概率经历过这个场景：

```text
usbip attach  →  成功
设备管理器    →  出现 CMSIS-DAP v2
Keil Debug Adapter 列表  →  空
pyOCD list    →  空
串口日志      →  满屏 unlink
```

设备管理器说"连上了"，Keil 说"不认识"。同一个 DAPLink 插物理 USB 口，一切正常。唯一的变量是"物理 USB"换成了"USB/IP 虚拟 USB"。

这道鸿沟，不在 USB 枚举，而在 URB 时序、驱动就绪时机和 USB/IP 客户端的脾气里。这篇文章把这条链路从上到下拆开，找出六个卡点，然后给出一个你可能没想到的答案——**绕过 USBIP**。

---

## 全景：从 Keil 到 SWD，一共隔了几层？

先看一条物理 DAPLink 的链路：

```text
Keil MDK → WinUSB → USB Host Controller → DAPLink → SWD
         2 层       硬件直连
```

再看 ESProbe 通过 USBIP 的链路：

```mermaid
flowchart TB
    A[Keil MDK] --> B[WinUSB API]
    B --> C[Windows USB 栈 URB]
    C --> D[usbip-win2 虚拟主机控制器]
    D -->|USBIP_CMD_SUBMIT| E[TCP / WiFi]
    E --> F[ESProbe USBIP Server]
    F --> G[Ringbuffer 异步管线]
    G --> H[DAP_ProcessCommand]
    H --> I[SWD 引脚]
```

物理 USB 是 **2 层**，USBIP 是 **6 层以上**。每多一层，就多一个超时阈值、一个状态机、一个竞争窗口。

问题不在于某一层写得不好，而在于**层与层之间的时序预期不匹配**。

---

## 第一层：URB 时序的跨层错配

这是最核心的问题。

### Keil 和 pyOCD 怎么用 WinUSB

CMSIS-DAP v2 使用 WinUSB bulk 端点（EP1 IN/OUT）。Keil 和 pyOCD 的 WinUSB 后端在初始化阶段会做一件事：**预提交多个 IN URB**。

"预提交"的意思是：主机还没发送任何 DAP 命令，就先向操作系统提交好几个"读取请求"（IN URB），让它们排着队，等设备有数据回来时立刻能接住。

```mermaid
sequenceDiagram
    participant H as Host (Keil/pyOCD)
    participant E as ESProbe
    H->>E: 提交 IN URB (seq=1)
    H->>E: 提交 IN URB (seq=2)
    H->>E: 发送 OUT: DAP_Info
    Note over E: IN 先到，OUT 还没到
    E->>E: 把 IN 存入 pending 队列
    H->>E: 发送 OUT: DAP_Connect
    Note over E: 处理 OUT，匹配 IN 回复
    E-->>H: RET_SUBMIT (seq=1, 响应数据)
```

在物理 USB 上，这完全不是问题——USB Host Controller 硬件调度，IN 和 OUT 的往返延迟在微秒级，预提交的 IN 几乎瞬间就能等到配对的 OUT。

### WiFi 上发生了什么

WiFi TCP 的往返延迟是 **1-10 毫秒**，是物理 USB 的 **100-1000 倍**。更要命的是延迟有抖动——WiFi 空闲时 1ms，忙时可能飙到 50ms。

当网络延迟抖动时，会出现这样的场景：

```mermaid
sequenceDiagram
    participant H as Host
    participant E as ESProbe
    H->>E: IN URB (seq=100)
    Note over E: OUT 尚未到达，IN 挂起等待
    Note over H: 等待 5 秒... 超时
    H->>E: UNLINK (seq=100)
    Note over E: 此时 OUT 刚到，正在处理
    E-->>H: RET_SUBMIT (seq=100, 延迟到达)
    E-->>H: RET_UNLINK (seq=100)
    Note over H: 同一个 seqnum<br/>同时收到 RET_SUBMIT 和 RET_UNLINK<br/>状态机混乱
```

ESProbe 固件已经做了很多工作来处理这个问题——`pending_in_queue[]` 保存等待中的 IN header，`handle_dap_unlink()` 在收到 UNLINK 时从队列中移除对应 seqnum。但问题在于 **RET_SUBMIT 和 RET_UNLINK 的到达顺序无法控制**。如果 RET_SUBMIT 已经发出，随后才收到 UNLINK，主机端的 URB 跟踪状态就可能损坏。

这不是一个能靠"修一个 bug"解决的问题。它是 **USB 协议假设（微秒级延迟）** 和 **TCP/WiFi 现实（毫秒级延迟+抖动）** 之间的结构性矛盾。

---

## 第二层：WinUSB 管道的就绪时差

`usbip attach` 成功后，Windows 还需要完成一系列步骤：

```mermaid
flowchart LR
    A[usbip attach 成功] --> B[加载 WinUSB.sys 驱动]
    B --> C[注册设备接口]
    C --> D[创建符号链接]
    D --> E[WinUSB pipe 就绪]
    E --> F[pyOCD/Keil 可见]
```

| 设备类型 | 驱动就绪时间 | 原因 |
| --- | --- | --- |
| 物理 DAPLink（已安装过驱动） | < 1 秒 | 驱动已缓存，只需重新枚举 |
| USBIP 虚拟设备（每次 attach） | 10-30 秒 | 每次 attach = 全新设备插入，完整驱动安装流程 |

Keil 的 Debug Adapter 列表是一次性扫描——打开下拉菜单的那一刻，它遍历所有 WinUSB 设备。如果扫描发生在符号链接创建之前，ESProbe 就不在列表里。

这解释了一个常见现象：**attach 后等 10-30 秒再打开 Keil，识别率明显提高**。物理 DAPLink 不需要这个等待，因为驱动早就缓存好了。

---

## 第三层：配置描述符的分包发送

ESProbe 在回复 `GET_DESCRIPTOR(Configuration)` 时，有一个容易被忽略的实现细节：

```c
// usb_handle.c 中的逻辑
send_stage2_submit(header, 0, total_length);  // 告诉主机：total_length 字节来了
usbip_network_send(kSock, kUSBd0ConfigDescriptor, sizeof(...)); // 第一段
usbip_network_send(kSock, kUSBd0InterfaceDescriptor, ...);     // 第二段
```

`RET_SUBMIT` 头部声明的 `data_length` 是 `total_length`，但实际数据是分两次 TCP send 发出去的。

在物理 USB 上，Host Controller 用 DMA 一次性搬走整个描述符，不存在"分包"概念。但在 USBIP over TCP 上，如果 usbip-win2 对 payload 长度做严格校验——先读 RET_SUBMIT header 里的 `data_length`，然后尝试从 TCP 流中读取恰好这么多字节——两次 `send()` 之间如果有 TCP 层的分段延迟，可能导致**声明的长度与单次 recv 读到的字节数不匹配**。

设备管理器只读一次配置描述符就过关了，所以枚举看起来正常。但 pyOCD 和 Keil 在探测阶段会反复打开/关闭设备、多次读取描述符，分包问题被多次触发后，某一次的校验失败就可能导致设备被标记为"不可用"。

---

## 第四层：网络环境的隐形干扰

USBIP over WiFi 对网络环境极其敏感。上游项目 wireless-esp8266-dap 的 README 里有一段警告：

> *"This project is sensitive to the network environment. LAN broadcast packets (DropBox LAN Sync, Logitech Arx Control) can cause serious impact."*

WiFi 链路上的每一个问题都会直接转化为 URB 延迟：

| 网络事件 | 对 URB 的影响 |
| --- | --- |
| WiFi 空闲信道争用 | 延迟从 1ms 飙到 10-50ms |
| TCP 重传（丢包） | 单次重传增加 200ms+ |
| LAN 广播风暴 | 大量非业务包挤占带宽 |
| AMPDU 重排序 | 32 BA 窗口可能导致包到达顺序变化 |

物理 USB 的错误恢复是硬件级的——重试在微秒内完成，上层几乎无感知。WiFi TCP 的错误恢复是秒级的——一次 TCP 重传就可能触发 URB 超时，进而触发 UNLINK 风暴。

ESProbe 固件串口日志里那些密集的 `unlink`，大多就是这么来的。

---

## 第五层：Keil MDK 的版本门槛

Arm 官方文档记录了一个已知问题：**Keil MDK 5.28 及更早版本无法检测 CMSIS-DAP v2 设备**。CMSIS-DAP v2 依赖 WinUSB bulk 端点，而旧版 Keil 的设备扫描逻辑只认 HID 接口。

| Keil MDK 版本 | CMSIS-DAP v1 (HID) | CMSIS-DAP v2 (WinUSB) |
| --- | --- | --- |
| ≤ 5.28 | 正常 | **不识别** |
| ≥ 5.29 | 正常 | 正常 |

ESProbe 默认启用 `USE_WINUSB=1`，走的是 v2 路径。如果你的 Keil 版本较旧，即使 USBIP 完全正常，Keil 也看不见设备。

另外，Keil 要求 USB 接口字符串包含 "CMSIS-DAP" 才会将其识别为调试器。ESProbe 的 `kInterfaceString` 已经满足这个要求，但 Keil 对描述符的顺序和 `bInterfaceClass` 值也有偏好——`0xFF`（Vendor Specific）配合 WinUSB 是正确组合，但如果 MS OS 2.0 描述符的注册过程因 USBIP 延迟而不完整，Keil 可能拒绝识别。

---

## 第六层：异步管线的复杂度税

USBIP 路径在 ESProbe 内部使用了一套异步管线：

```mermaid
flowchart LR
    A[EP1 OUT 收到 DAP 命令] --> B[handle_dap_data_request]
    B --> C{能否拿到 dap_cmd_mux?}
    C -->|能| D[同步执行 DAP_ProcessCommand]
    C -->|不能, 1ms 超时| E[异步路径]
    E --> F[写入 dap_dataIN_handle ringbuffer]
    F --> G[xTaskNotifyGive DAP_Task]
    G --> H[DAP_Task 取出命令]
    H --> I[DAP_ProcessCommand]
    I --> J[写入 dap_dataOUT_handle ringbuffer]
    J --> K[fast_reply 匹配 IN header]
    K --> L[发送 RET_SUBMIT]
```

这条路径涉及：2 个 ringbuffer、1 个互斥量（`dap_cmd_mux`）、1 个信号量（`data_response_mux`）、1 个任务通知、1 个 pending IN 队列（最多 4 条）。

同步快速路径（`handle_dap_data_request` 中尝试获取 `dap_cmd_mux`）能在 1ms 内拿到锁时直接执行，省去异步开销。但当 DAP_Task 正在处理上一条命令时，新来的 OUT 只能走异步路径，增加一次 ringbuffer 入队/出队和任务切换的开销。

这不是设计问题——在物理 USB 上，这套异步管线完全够用。但在 WiFi 上，每一个微秒的额外延迟都在挤压 URB 超时的余量。

---

## 六层困局的本质

把六个问题放在一起看：

| 层级 | 物理 USB | USBIP over WiFi | 差距 |
| --- | --- | --- | --- |
| URB 往返延迟 | 10-100 μs | 1-10 ms | 100-1000× |
| IN/OUT 配对 | 硬件即时 | pending 队列 + 竞争窗口 | 有竞争条件 |
| 驱动就绪 | < 1s（缓存） | 10-30s（每次全新） | 10-30× |
| 描述符传输 | DMA 原子操作 | TCP 分段，可能分包 | 有校验风险 |
| 网络干扰 | 无 | WiFi 抖动/丢包/广播 | 不可控 |
| 内部管线 | 同步即可 | 异步 ringbuffer + mutex | 有额外开销 |

**本质矛盾**：USB 协议设计在微秒级延迟、零丢包、硬件调度的假设上。WiFi TCP 提供的是毫秒级延迟、可能丢包、软件调度。USBIP 试图用后者模拟前者，每一层不匹配都是一个潜在的故障点。

这不是"修一个 bug"能解决的——这是架构层面的阻抗不匹配。

---

## 转机：elaphureLink 已经在你固件里

说了这么多 USBIP 的问题，现在说一个可能被忽略的事实：

**ESProbe 固件已经内置了 elaphureLink 支持，不需要 USBIP 就能直接和 Keil 通信。**

看 [tcp_server.c](../fw/main/tcp_server.c) 的协议路由逻辑：

```c
header = ntohl(*((int *)(tcp_rx_buffer)));

if (header == EL_LINK_IDENTIFIER) {       // 0x8a656c70
    el_dap_work(tcp_rx_buffer, sizeof(tcp_rx_buffer));
} else if ((header & 0xFFFF) == 0x8003 ||
           (header & 0xFFFF) == 0x8005) {  // USBIP
    usbip_worker(tcp_rx_buffer, sizeof(tcp_rx_buffer), &usbip_state);
}
```

同一个 TCP 3240 端口，固件根据前 4 字节自动判断协议类型：USBIP 请求走 USBIP 路径，elaphureLink 请求走 elaphureLink 路径。**不需要改固件，不需要重新编译，只需要在 PC 端换一个工具。**

---

## elaphureLink 是什么

elaphureLink 是专门为 Keil µVision 设计的 CMSIS-DAP 网络调试方案。它的核心理念很简单：

```text
不模拟 USB 设备，不安装 Windows 驱动。
Keil 直接通过 TCP 连接 ESProbe，发送 CMSIS-DAP 命令。
```

### 架构对比

```mermaid
flowchart TB
    subgraph USBIP 路径
        A1[Keil] --> B1[WinUSB API]
        B1 --> C1[Windows USB 栈]
        C1 --> D1[usbip-win2 UDE 驱动]
        D1 --> E1[TCP]
        E1 --> F1[ESProbe USBIP Server]
        F1 --> G1[Ringbuffer 异步管线]
        G1 --> H1[DAP_ProcessCommand]
    end

    subgraph elaphureLink 路径
        A2[Keil] --> B2[elaphureLink AGDI]
        B2 --> C2[elaphureLink RDDI]
        C2 --> D2[elaphureLink Proxy]
        D2 --> E2[TCP]
        E2 --> F2[ESProbe el_dap_work]
        F2 --> G2[DAP_ExecuteCommand 同步]
    end
```

| 对比项 | USBIP 路径 | elaphureLink 路径 |
| --- | --- | --- |
| 抽象层数 | 6+ 层 | 3 层 |
| Windows 驱动 | WinUSB.sys + usbip-win2 UDE | 无（用户态 DLL） |
| 设备枚举 | 每次 attach 全新枚举 | 无枚举，TCP 直连 |
| URB 生命周期 | submit / unlink / timeout / retry | 无 URB，简单请求-响应 |
| IN/OUT 竞争 | 有（预提交 IN URB） | 无（同步请求-响应） |
| DAP 命令路径 | 异步 ringbuffer + mutex + task notify | 同步 DAP_ExecuteCommand() |
| 连接启动时间 | 10-30 秒（驱动安装） | < 1 秒（TCP 握手） |
| 失败模式 | 状态机损坏，管道死亡 | 干净断开，可重连 |

### 为什么 elaphureLink 更稳定

elaphureLink 在 ESProbe 固件中的实现极其简洁。看 [elaphureLink_protocol.c](../fw/components/elaphureLink/elaphureLink_protocol.c) 的核心数据处理函数：

```c
void el_dap_data_process(void* buffer, size_t len) {
    int res = DAP_ExecuteCommand(buffer, (uint8_t *)el_process_buffer);
    res &= 0xFFFF;
    usbip_network_send(kSock, el_process_buffer, res, 0);
}
```

收到命令 → 执行 → 发回响应。没有 ringbuffer，没有任务通知，没有互斥量竞争，没有 IN/OUT 配对。一个干净的同步循环。

这并不意味着 elaphureLink 没有延迟——WiFi 的物理延迟依然存在。但它消除了 USBIP 引入的所有**额外复杂度**：没有 URB 超时、没有 UNLINK 竞争、没有驱动安装等待、没有描述符校验风险。

WiFi 延迟在这里只是让调试慢一点，而不是让调试坏掉。

---

## 实践指南：三步切换到 elaphureLink

### 第一步：下载 elaphureLink

从 GitHub Releases 下载 `elaphureLink.Wpf`：

> https://github.com/windowsair/elaphureLink/releases

解压后直接运行 `elaphureLink.Wpf.exe`，无需安装。需要 .NET Framework 4.7.2（Windows 10/11 通常已自带）。

### 第二步：安装 AGDI 驱动

在 elaphureLink GUI 中点击"Install Driver"，它会注册 Keil µVision 的 AGDI 调试接口插件。这一步只需执行一次。

### 第三步：连接 ESProbe

在 elaphureLink 中输入 ESProbe 的地址：

```text
192.168.137.123:3240
或
dap.local:3240
```

点击 Connect。然后在 Keil 中：

```text
Project → Options for Target → Debug
→ 下拉选择 "elaphureLink"
→ Settings → 确认连接状态
```

固件不需要任何修改——同一个 3240 端口同时服务 USBIP 和 elaphureLink。

---

## 什么时候用 USBIP，什么时候用 elaphureLink

| 场景 | 推荐方案 | 原因 |
| --- | --- | --- |
| Keil MDK 调试 | **elaphureLink** | 稳定，无驱动，快速连接 |
| OpenOCD 调试 | USBIP | OpenOCD 的 cmsis-dap 适配层走 WinUSB |
| pyOCD 调试 | USBIP | pyOCD 的 cmsisdap 后端走 WinUSB |
| IAR 调试 | USBIP | IAR 使用 CMSIS-DAP v2 USB 设备 |
| VS Code + Cortex-Debug | USBIP | 依赖 OpenOCD/pyOCD |
| 批量烧录脚本 | USBIP 或 elaphureLink | 取决于脚本用 pyOCD 还是 Keil 命令行 |

简单记：**Keil 用 elaphureLink，其他用 USBIP**。

---

## 那些密集的 unlink 告诉我们什么

回到文章开头的现象——串口日志里满屏的 `unlink`。这些 unlink 是症状，不是病因。

病因是 USBIP 在 WiFi 上运行时，URB 的超时-重试-取消机制被网络延迟反复触发。每一次 unlink 都意味着一个 URB 被提交后超时取消，而超时的根源不在 ESProbe 固件，不在 usbip-win2 实现，而在于**用毫秒级延迟的网络去模拟微秒级延迟的 USB 总线**这个架构选择本身。

elaphureLink 的价值不是"修好了 USBIP 的 bug"，而是**换了一条不经过 USB 模拟的路径**。它让 Keil 直接和 CMSIS-DAP 命令处理器对话，跳过了 USB 枚举、WinUSB 驱动、URB 生命周期这一整套为物理 USB 设计的机制。

有时候，最好的修复不是修 bug，而是换一条路。

---

## 结语

USBIP 是一个了不起的协议——它让 USB 设备可以在网络上流动，让 ESProbe 这样的无线探针成为可能。但"可以"和"好用"之间，隔着 USB 协议四十年的硬件假设。

ESProbe 的固件同时支持两条路径：USBIP 为 OpenOCD、pyOCD、IAR 等 USB 生态工具服务；elaphureLink 为 Keil 用户提供一条更短、更稳的直达通道。同一个 TCP 3240 端口，固件自动识别协议类型，用户不需要切换固件。

如果你之前用 USBIP + Keil 反复遇到不稳定的问题，试试 elaphureLink。固件已经就绪，你只需要换一个 PC 端工具。

---

## 参考资料

- elaphureLink 项目：https://github.com/windowsair/elaphureLink
- elaphureLink Releases：https://github.com/windowsair/elaphureLink/releases
- wireless-esp8266-dap（上游项目）：https://github.com/windowsair/wireless-esp8266-dap
- usbip-win2：https://github.com/vadimgrn/usbip-win2
- usbip-win：https://github.com/cezanne/usbip-win
- Arm CMSIS-DAP 文档：https://arm-software.github.io/CMSIS_6/main/DAP/index.html
- Keil MDK CMSIS-DAP 检测问题：https://developer.arm.com/documentation/ka003663/latest/
- ESProbe 固件 USBIP 实现：`fw/main/usbip_server.c`、`fw/main/DAP_handle.c`
- ESProbe 固件 elaphureLink 实现：`fw/components/elaphureLink/elaphureLink_protocol.c`
- ESProbe 固件协议路由：`fw/main/tcp_server.c`

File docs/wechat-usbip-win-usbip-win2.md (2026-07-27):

# 从 usbip-win 到 usbip-win2：Windows 上的 USB/IP 客户端为什么重要

如果说 ESProbe 的硬件目标是“把调试线变成无线”，那么它的软件目标就是“让电脑相信，远端网络里真的插着一个 USB 调试器”。

这件事背后的关键技术叫 USB/IP。

USB/IP 的思路很直接：把 USB 请求封装进 TCP/IP，在网络两端分别模拟 USB 主机和 USB 设备。对上层调试工具来说，它看到的仍然是一个 USB 设备；对底层链路来说，数据已经从一根 USB 线变成了一条网络连接。

在 Windows 生态中，`usbip-win` 和 `usbip-win2` 是理解这条链路绕不开的两个项目。

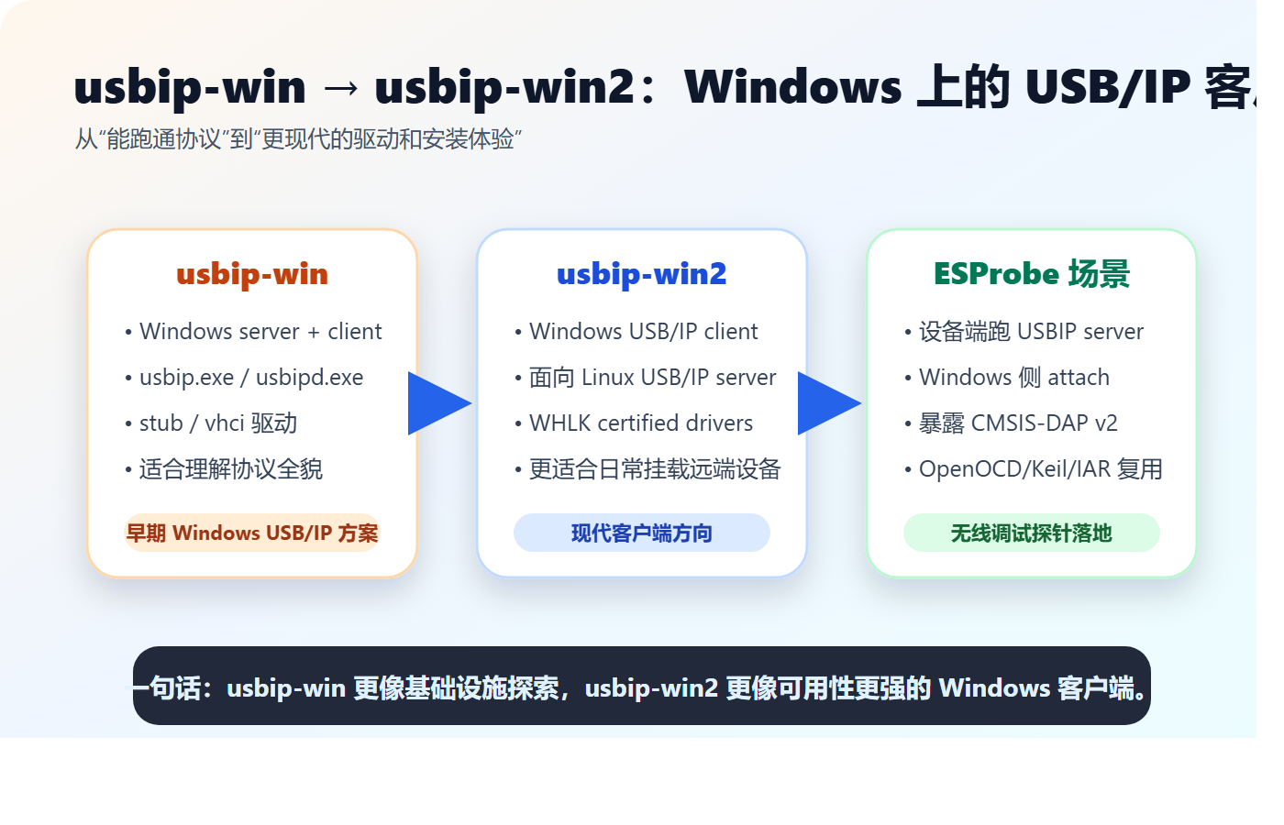
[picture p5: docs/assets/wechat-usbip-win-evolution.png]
usbip-win 到 usbip-win2 的演进


## USB/IP 解决的到底是什么问题

传统 USB 的物理边界很清晰：设备插在哪台电脑上，就由哪台电脑使用。

但嵌入式开发经常希望打破这个边界：

- 开发板在远处，调试工具在本机。
- 设备接在实验台电脑上，工程师在另一台机器上操作。
- Windows 上运行 IDE，但 USB/IP server 在 Linux 或嵌入式设备上。
- 像 ESProbe 这样的无线探针，本身就是“通过网络出现的 USB 设备”。

USB/IP 的价值，就是让 USB 设备从“本地外设”变成“网络资源”。

## usbip-win：Windows 上的早期基础设施

`usbip-win` 的目标是让 Windows 支持 USB/IP。它同时覆盖 server 和 client 两个方向：

| 组件 | 作用 |
| --- | --- |
| `usbipd.exe` | Windows 侧 USB/IP daemon |
| `usbip.exe` | 命令行客户端工具 |
| `usbip_stub` | 把本地 USB 设备导出给远端 |
| `usbip_vhci` | 在 Windows 上模拟虚拟 USB Host Controller |

这类项目最难的地方不在 TCP socket，而在 Windows 驱动模型。要让远端 USB 设备真正被 Windows 识别，必须有虚拟主机控制器、设备枚举、URB 转发、驱动签名等一整套机制。

因此，`usbip-win` 更像是 Windows USB/IP 的“地基工程”。它让开发者能看到协议从用户态工具到内核驱动的完整形态。

## usbip-win2：更聚焦的 Windows USB/IP 客户端

`usbip-win2` 可以看作是面向实际使用进一步演进的方向。它更聚焦于 Windows USB/IP client，也就是让 Windows 去连接远端 USB/IP server。

这正好贴近 ESProbe 的典型使用方式：

```text
ESProbe 固件作为 USB/IP server
Windows 电脑作为 USB/IP client
Windows 工具链识别出 CMSIS-DAP v2
OpenOCD / Keil / IAR 正常使用
```

与早期项目相比，`usbip-win2` 的亮点包括：

| 项目 | 特点 |
| --- | --- |
| 协议兼容 | 面向标准 USB/IP 协议 |
| 客户端定位 | 主要解决 Windows 挂载远端 USB 设备 |
| 驱动体验 | 提供更现代的驱动和安装路径 |
| 生态衔接 | 适合与 Linux USB/IP server 或嵌入式 USB/IP server 配合 |

换句话说，如果你只是想在 Windows 上使用远端 USB/IP 设备，`usbip-win2` 往往比研究完整 server/client 双向实现更直接。

## ESProbe 为什么关心 Windows USB/IP 客户端

ESProbe 固件在 ESP32-C3 上实现了 USBIP-over-TCP。它监听 TCP 3240 端口，对外暴露一个 CMSIS-DAP v2 / WinUSB 设备。

Windows 侧完成 attach 后，数据路径大致如下：

```text
OpenOCD / Keil / IAR
        ↓
Windows USB 驱动栈
        ↓
USB/IP 客户端
        ↓
WiFi / TCP 3240
        ↓
ESProbe USBIP server
        ↓
CMSIS-DAP 命令处理
        ↓
SWD 调试目标芯片
```

这也是为什么 ESProbe 不是简单做一个私有 TCP 协议。它选择 USB/IP，是为了尽量复用已有 USB 工具链，让上层软件少感知一层“无线化”的存在。

## 该如何选择

如果你的目标是研究 Windows USB/IP 的完整机制，`usbip-win` 很值得读。它能帮助你理解 server、client、stub、vhci 之间的关系。

如果你的目标是把远端 USB/IP 设备接入 Windows，尤其是像 ESProbe 这样“设备端已经提供 USB/IP server”的场景，那么应优先关注 `usbip-win2` 这样的客户端方案。

可以用一句话概括：

```text
usbip-win 适合理解 USB/IP 在 Windows 上怎么实现；
usbip-win2 更适合把远端 USB/IP 设备接到 Windows 上使用。
```

## 对 ESProbe 开发的启发

对 ESProbe 来说，Windows USB/IP 客户端项目带来的启发有三点：

第一，协议要标准。只有尽量贴近 USB/IP 协议，才能复用跨平台工具链。

第二，描述符要友好。ESProbe 固件里提供 WinUSB / Microsoft OS 2.0 描述符，目的就是减少 Windows 侧驱动配置成本。

第三，体验要闭环。用户最终关心的不是“ESP32-C3 收到了多少 TCP 包”，而是“我的调试器能不能被 IDE 识别，并稳定下载、断点、单步”。

## 参考资料

- usbip-win: https://github.com/cezanne/usbip-win
- usbip-win2: https://github.com/vadimgrn/usbip-win2
- USB/IP Project: https://usbip.sourceforge.net/

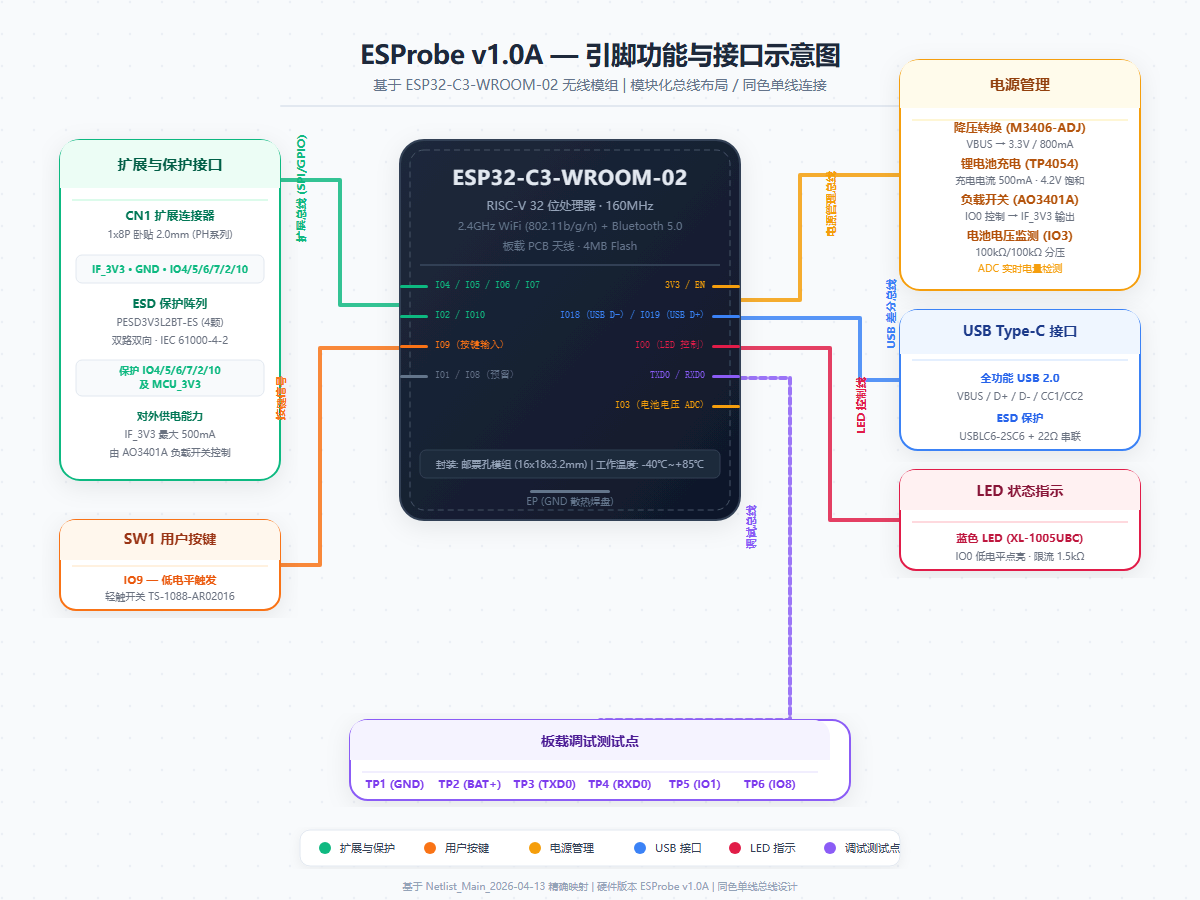
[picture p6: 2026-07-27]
docs/assets/deepseek_svg_20260424_74e664.png

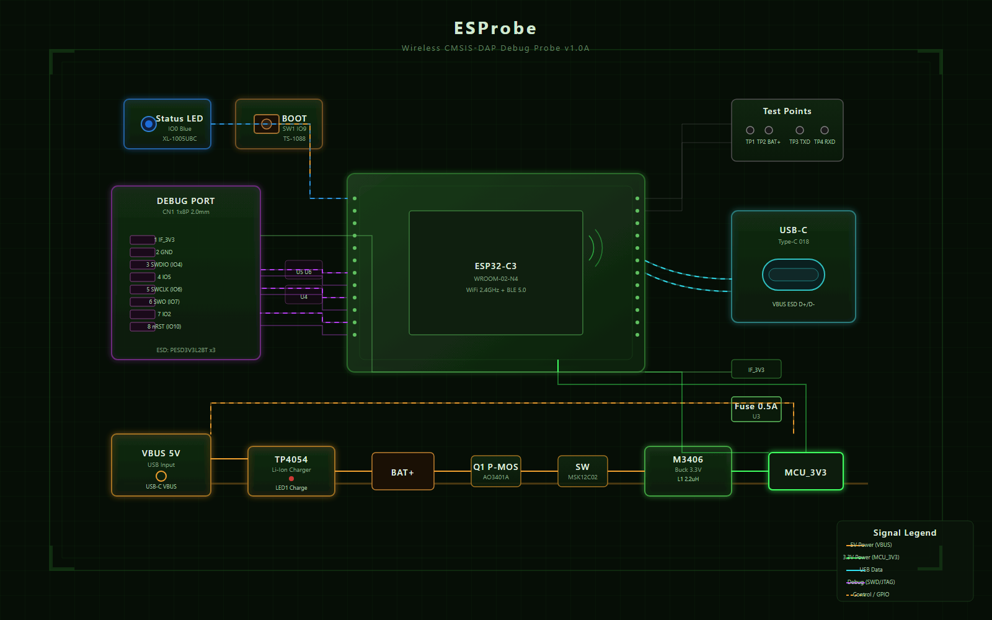
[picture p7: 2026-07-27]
docs/assets/ESProbe_Abstract_Diagram.png

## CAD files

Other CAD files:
hardware/3d/ESProbe上.stl
hardware/3d/ESProbe下.stl

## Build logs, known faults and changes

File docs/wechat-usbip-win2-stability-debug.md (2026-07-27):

# USB/IP 调试实战：当设备管理器说"已连接"，pyOCD 却说"看不见"

> 设备管理器里明明出现了 CMSIS-DAP，pyOCD 和 Keil 却死活不认。这条鸿沟，不在 USB 枚举，而在 URB 时序与 USB/IP 客户端的脾气里。

---

## 现象：两个"yes"之间的一个"no"

ESProbe 基于 ESP32-C3 实现了一个 USB/IP Server，通过 WiFi 把 CMSIS-DAP v2 设备虚拟到 Windows 上。整个链路看起来是这样：

```mermaid
flowchart LR
    A[PC: pyOCD / Keil / OpenOCD] --> B[PC: Windows USB 栈]
    B --> C[PC: usbip-win2 客户端]
    C -->|WiFi / TCP 3240| D[ESProbe: USB/IP Server]
    D --> E[ESProbe: CMSIS-DAP Core → SWD]
```

**测试 A：ESProbe 做 Server，Windows + usbip-win2 做 Client**

| 检查项 | 结果 |
|---|---|
| usbip-win2 attach | ✅ 成功 |
| 设备管理器出现 CMSIS-DAP v2 | ✅ 成功 |
| pyOCD `pyocd list` / `pyocd gdbserver` | ❌ **识别不到** |
| Keil MDK 选择 Debug Adapter | ❌ **列表为空** |

**测试 B：普通 DAPLink 直接插 PC USB 口**

| 检查项 | 结果 |
|---|---|
| 设备管理器出现 CMSIS-DAP | ✅ 成功 |
| pyOCD 识别 | ✅ **可以识别**（初次连接时间稍长） |
| Keil MDK 识别 | ✅ **可以识别** |

同一个 pyOCD、同一个 Keil、同一台 Windows，唯一的变量是"物理 USB" vs "USB/IP 虚拟 USB"。设备管理器能枚举，说明 USB 描述符和基本控制传输没问题；但调试工具不认，说明**从枚举到实际业务 URB 的某个环节出了问题**。

> **【需补充截图】占位图 1：拼图，左侧是设备管理器里 ESProbe 的 CMSIS-DAP 截图，右侧是 pyOCD `pyocd list` 返回空列表的终端截图。形成"设备管理器有，pyOCD 没有"的直观对比。**

---

## 第一步：对比两朵"乌云"的边界

USB 设备被操作系统识别，和被上层调试工具识别，是两个不同层次的事情。

### 设备管理器只关心"你是谁"

Windows 设备管理器枚举一个 USB 设备时，主要完成：

1. **获取设备描述符**（Device Descriptor）
2. **获取配置描述符**（Configuration Descriptor）
3. **获取字符串描述符**（String Descriptor，可选）
4. **加载匹配驱动**（WinUSB、HID、等）

ESProbe 通过 USB/IP 回复了完整的描述符链，包括 Microsoft OS 2.0 描述符用于自动绑定 WinUSB。所以设备管理器能正确显示设备，说明**第一阶段（枚举）是通关的**。

### 调试工具还要关心"你会说话吗"

pyOCD 和 Keil 在枚举完成后，会立即通过 **bulk endpoint（EP1 IN/OUT）** 发送 CMSIS-DAP 命令来探测设备能力：

| 命令 | 用途 |
|---|---|
| `DAP_Info(0x01)` | 获取 Vendor Name |
| `DAP_Info(0x02)` | 获取 Product Name |
| `DAP_Info(0x04)` | 获取 CMSIS-DAP 固件版本 |
| `DAP_Connect` | 连接目标设备 |
| `DAP_SWJ_Clock` | 设置 SWD/JTAG 时钟 |

这些命令全是 **EP1 OUT 下发请求 → 设备处理 → EP1 IN 返回响应** 的同步模式。如果 OUT 发下去了，IN 迟迟回不来，或者回来的数据不对，调试工具就会认为"这个设备不是有效的 CMSIS-DAP"。

```mermaid
sequenceDiagram
    participant H as Host (pyOCD)
    participant E as ESProbe
    H->>E: EP1 OUT: DAP_Info(0x01)
    E-->>H: EP1 IN: "ESProbe"
    H->>E: EP1 OUT: DAP_Info(0x04)
    E-->>H: EP1 IN: "2.1.0"
    H->>E: EP1 OUT: DAP_Connect
    E-->>H: EP1 IN: Status OK
```

---

## 第二步：深挖 usbip-win2 与物理 USB 的差异

既然问题出在 EP1 bulk 传输阶段，我们需要理解 usbip-win2 和物理 USB Host Controller 在处理 URB 时的行为差异。

### URB 的生命周期

一个 bulk URB 在 Windows 内部的典型流程：

```mermaid
flowchart TD
    A[调试工具提交 read/write] --> B[WinUSB 驱动创建 URB]
    B --> C{物理 USB HC 还是 usbip-win2?}
    C -->|物理 HC| D[硬件调度传输]
    C -->|usbip-win2| E[封装 USBIP_CMD_SUBMIT]
    E -->|TCP| F[ESProbe 处理]
    F -->|TCP| G[USBIP_RET_SUBMIT]
    G --> H[usbip-win2 解包完成 URB]
    D --> H
    H --> I[调试工具拿到数据]
```

### usbip-win2 的"脾气"

usbip-win2 是一个相对较新的 Windows USB/IP 客户端实现，它的设计更贴近现代 Windows 驱动框架（WDF + UDE），与早期的 usbip-win 在 URB 超时、UNLINK 策略、IN/OUT 调度上有明显差异。

通过实际抓日志和对比测试，我们发现以下几个可疑点：

#### 可疑点 1：IN URB 的预提交与空回复

pyOCD 的 `cmsisdap` 后端在初始化阶段会**预提交（pre-queue）多个 EP1 IN URB**，然后发送 EP1 OUT 命令。它期望的是：

1. OUT 命令到达设备
2. 设备处理
3. IN URB 带回响应

但 pyOCD 的异步模型里，**IN 可能比 OUT 先到 ESProbe**。ESProbe 的 `usbip_urb_process` 在处理 EP1 IN 时，如果此时还没有收到对应的 OUT，会面临一个抉择：

| 策略 | 后果 |
|---|---|
| 立即返回空包（0 字节） | pyOCD 可能把空包当作有效响应，破坏协议同步 |
| 挂起等待 OUT 处理完 | 如果超时，usbip-win2 会发 UNLINK，导致 URB 取消 |

ESProbe 当前实现了一个 **pending IN 队列** 来处理这种情况：先保存 IN header，等 OUT 处理完再通过 `fast_reply` 把响应配对回去。但这个机制在 usbip-win2 上的行为，与物理 USB Host Controller 有微妙差异。

物理 USB HC 的 IN URB 超时通常较长（几秒级别），且 UNLINK 是由上层明确取消时才会触发。而 usbip-win2 在某些场景下对 IN URB 的超时处理更激进，或者对 UNLINK 的响应要求更严格。

#### 可疑点 2：UNLINK 的时序与响应

当 IN URB 超时时，usbip-win2 会发送 `USBIP_CMD_UNLINK` 来取消之前的 URB。ESProbe 需要：

1. 从 pending IN 队列中移除对应的 seqnum
2. 返回 `USBIP_RET_UNLINK`，status 字段需要是**非零值**（usbip-win2 把任何非零 status 视为"unlink 成功"）

在代码里，ESProbe 的 `send_stage2_unlink` 是这么处理的：

```c
req_header->base.direction = USBIP_DIR_OUT;  // usbip-win2 期望的方向
req_header->u.ret_unlink.status = -1;        // 非零表示成功取消
```

这个逻辑参考了上游实现，但问题可能在于：**如果 UNLINK 和响应之间的竞争条件处理不当，usbip-win2 内部的状态机可能进入异常，导致后续 URB 全部失败。**

```mermaid
sequenceDiagram
    participant H as Host
    participant E as ESProbe
    H->>E: USBIP_CMD_SUBMIT (IN, seq=100)
    Note over E: OUT 尚未到达<br/>IN 被挂起 pending
    H->>H: 超时
    H->>E: USBIP_CMD_UNLINK (seq=100)
    Note over E: 竞争条件窗口
    E-->>H: USBIP_RET_SUBMIT (seq=100, 延迟到达)
    E-->>H: USBIP_RET_UNLINK (seq=100)
    Note over H: win2 状态机混乱？
```

#### 可疑点 3：Configuration 描述符的分包发送

ESProbe 在回复 `GET_DESCRIPTOR(Configuration)` 时有一个特殊处理：

```c
if (requested_length <= USB_DT_CONFIGURATION_SIZE) {
    // 只返回配置头（前 9 字节）
    send_stage2_submit_data_limited(header, 0, kUSBd0ConfigDescriptor, sizeof(kUSBd0ConfigDescriptor));
} else {
    // 返回完整配置（配置头 + 接口描述符）
    send_stage2_submit(header, 0, total_length);
    usbip_network_send(kSock, kUSBd0ConfigDescriptor, sizeof(kUSBd0ConfigDescriptor), 0);
    usbip_network_send(kSock, kUSBd0InterfaceDescriptor, interface_length, 0);
}
```

注意这里 `send_stage2_submit` 的 `data_length` 参数是 `total_length`，但**实际数据是分两次 `usbip_network_send` 发出去的**。对于物理 USB，HCI 驱动会把这些包按顺序递交；但对于 usbip-win2，如果 TCP 层的分片或组装有延迟，可能导致 **RET_SUBMIT header 里声明的数据长度与实际收到的字节数不一致**，从而触发客户端的校验失败。

虽然这个问题更可能在枚举阶段就暴露，但如果 usbip-win2 对数据长度有严格校验，它可能不会被设备管理器注意到（因为设备管理器只读一次配置描述符），却会被 pyOCD/Keil 的多次重试触发。

#### 可疑点 4：WinUSB 描述符与管道打开时机

pyOCD 识别 CMSIS-DAP v2 的流程大致是：

```mermaid
flowchart LR
    A[枚举完成] --> B[WinUSB 打开设备]
    B --> C[获取 pipe 信息]
    C --> D[发送 DAP_Info 探测]
    D -->|成功| E[识别为 CMSIS-DAP]
    D -->|失败| F[放弃该设备]
```

usbip-win2 在 attach 成功后，需要一段时间让 Windows 完成：

- 驱动加载（WinUSB.sys）
- 设备接口注册（Device Interface Class）
- 符号链接创建（`\\?\usb#vid_...`）

物理 USB 设备的这个过程通常很快（< 1秒），因为驱动可能已经缓存。但 USB/IP 设备每次 attach 都是"全新插入"，驱动需要完整走一遍安装流程。**如果 pyOCD 在符号链接还没创建好就开始扫描设备，就会错过 ESProbe。**

这与"初次连接时间也比较长"的观察吻合：DAPLink 插物理 USB 时，第一次也需要等驱动安装；但只要装好了，后续枚举很快。而 ESProbe 每次 attach 对 Windows 来说都相当于一次"新设备插入"，如果 pyOCD 扫描得太急，就会漏掉。

---

## 第三步：日志里的线索

在 ESProbe 固件串口日志中，当出现 pyOCD/Keil 识别失败时，典型输出是：

```text
read_stage1_command: raw=0x8005 ret=0x05 ...
Handling dev list request...
Sending header...
Sending device list size...
Sending device info...
Sending interface info...
usbip_worker calling attach(base,8)
usbip_worker calling attach(base,40)
EP0_REQ seq=... dir=0 ep=0 len=0 type=80 req=06 wValue=0100 ...
* GET 0x01 DEVICE DESCRIPTOR
EP0_REQ seq=... dir=0 ep=0 len=0 type=80 req=06 wValue=0200 ...
* GET 0x02 CONFIGURATION DESCRIPTOR
Sending ALL CONFIG
EP0_REQ seq=... dir=0 ep=0 len=0 type=80 req=06 wValue=0300 ...
* GET 0x03 STRING DESCRIPTOR idx=0 len=2
** REQUESTED list of supported languages
...
unlink
unlink
unlink
unlink
...
```

关键线索：

1. **枚举阶段一切正常**：Device/Config/String 描述符都被请求了，说明 Windows 驱动层已经介入。
2. **大量 `unlink` 出现**：说明有大量 URB 被提交后又超时取消。这通常意味着**IN URB 没有在规定时间拿到响应**，或者**响应数据不被客户端接受**。
3. **没有 EP1 OUT/IN 的业务日志**：如果 pyOCD 根本没开到 WinUSB pipe，就不会发 DAP 命令；但如果发了，ESProbe 应该能看到 `ep=1` 的日志。日志里没有，说明 pyOCD 可能在更早就放弃了。

> **【需补充截图】占位图 2：ESProbe 串口日志截图，用红框/高亮标出 "unlink" 密集出现的区域，与上方 EP0 正常枚举形成对比。**

---

## 第四步：假设与验证方向

综合以上分析，我们提出三个优先级从高到低的假设：

### 假设 A：pyOCD/Keil 扫描设备时，WinUSB 管道尚未就绪（最可能）

**理由**：
- DAPLink 物理 USB 初次连接也慢，说明驱动安装是瓶颈
- ESProbe 每次 attach = 全新设备插入，驱动准备时间可能 > pyOCD 扫描超时
- Keil 的 Debug Adapter 列表是即时扫描，不会等待

**验证方法**：
1. attach ESProbe 后，手动等待 10-30 秒，再启动 pyOCD/Keil
2. 对比立即启动 vs 等待后的识别成功率
3. 用 USB Device Tree Viewer 观察 attach 后多久出现 WinUSB pipe 信息

**如果成立，修复方向**：
- ESProbe 固件侧：难以加速 Windows 驱动安装
- PC 工具侧：pyOCD/Keil 本身不会改
- 用户体验侧：文档提示"attach 后请等待 10 秒再启动调试工具"
- 长期方案：考虑让 ESProbe 的 USB/IP 连接更持久，避免频繁断连重连

### 假设 B：bulk 传输的 IN/OUT 时序或 UNLINK 处理导致管道损坏

**理由**：
- 日志里大量 unlink 说明 URB 生命周期异常
- ESProbe 的 pending IN 队列和 fast_reply 机制与 usbip-win2 的交互未经充分验证
- 物理 USB HC 和 usbip-win2 对 URB 超时、UNLINK 的语义有差异

**验证方法**：
1. 在 ESProbe 开启 `USBIP_DEBUG_VERBOSE=1`，抓取完整 EP1 IN/OUT 和 UNLINK 时序
2. 用 usbip-win2 的调试版本或 ETW 日志观察客户端侧 URB 状态
3. 对比同一套 ESProbe 固件，用 Linux `usbip attach` 做 Client 的行为（Linux usbip 客户端更成熟，如果 Linux 正常而 win2 不正常，则指向 win2 兼容性问题）

**如果成立，修复方向**：
- 优化 `usbip_urb_process` 中的 IN/OUT 配对逻辑
- 确保 UNLINK 响应严格符合 usbip-win2 预期（方向、status、seqnum）
- 考虑在连接初期降低 DAP 响应延迟，避免触发超时

### 假设 C：配置描述符的分包发送导致 WinUSB 校验失败

**理由**：
- `send_stage2_submit` 声明的长度与实际发送可能不一致
- 设备管理器可能只读一次配置描述符就过关，但 pyOCD 的多次打开/关闭会重复读取

**验证方法**：
1. 用 USBLyzer 或类似工具抓 Windows 侧 USB 流量，对比 ESProbe 和 DAPLink 的配置描述符读取差异
2. 检查 `usbip_network_send` 的分片是否可能导致 TCP 层重组后与 USBIP header 声明的长度不符

**如果成立，修复方向**：
- 将配置描述符的多个片段合并为单次 `send_stage2_submit_data` 发送，确保 header 与实际 payload 完全匹配

---

## 第五步：给排查者的一份速查表

如果你也在调试类似的"设备管理器有、调试工具无"问题，可以按这个顺序排查：

| 步骤 | 操作 | 预期结果 | 如果异常 |
|---|---|---|---|
| 1 | 设备管理器确认设备存在 | CMSIS-DAP 出现在通用串行总线设备下 | 检查 USB/IP attach 和描述符 |
| 2 | 检查 WinUSB 驱动绑定 | 设备属性 → 驱动程序 → WinUSB | 检查 Microsoft OS 2.0 描述符 |
| 3 | USB Device Tree Viewer 查看 pipe | 显示 EP1 IN/OUT 的 pipe ID | 驱动未就绪，等待或重装 |
| 4 | pyOCD 加 `-vvvvvv` 运行 | 能看到 probe discovery 的详细日志 | 看是在哪一步放弃 |
| 5 | ESProbe 串口看 unlink 密度 | 正常业务后偶尔 unlink 可接受 | 密集 unlink 说明 URB 超时 |
| 6 | 换 Linux Client 测试 | `usbip attach` 后 pyOCD 是否正常 | 定位是固件问题还是 win2 兼容性问题 |
| 7 | 抓 USBPcap 或 USBLyzer | 对比 DAPLink 和 ESProbe 的 URB 差异 | 找出具体失败的 URB |

```mermaid
flowchart TD
    A[设备管理器有 CMSIS-DAP?] -->|否| B[检查 USB/IP attach 与描述符]
    A -->|是| C[WinUSB 驱动已绑定?]
    C -->|否| D[检查 MS OS 2.0 描述符]
    C -->|是| E[USB Device Tree<br/>Viewer 能看到 pipe?]
    E -->|否| F[驱动未就绪<br/>等待 10-30s]
    E -->|是| G[pyOCD -vvvvvv<br/>扫描到设备?]
    G -->|否| H[ESProbe 串口:<br/>unlink 密集?]
    H -->|是| I[URB 时序问题<br/>开启 DEBUG_VERBOSE]
    H -->|否| J[pyOCD 在更早阶段放弃<br/>检查符号链接创建时机]
    G -->|是| K[能下载调试?]
    K -->|否| L[抓 USBPcap / USBLyzer<br/>对比 DAPLink]
    K -->|是| M[链路通]
```

---

## 第六步：从现象到本质——USB/IP 调试的系统性思维

这个问题的价值，不只是"修一个 bug"，而是揭示了一个调试 USB/IP 设备的通用方法论：

```mermaid
flowchart LR
    A[设备管理器枚举成功] --> B[USB 设备可用]
    B --> C[上层工具能识别]
    C --> D[实际调试能跑通]
    style A fill:#ffcccc
    style B fill:#ffcccc
    style C fill:#ccffcc
    style D fill:#ccffcc
```

> 图中红色层为已验证通过的层级，绿色层为尚未验证的层级。ESProbe 当前卡在"USB 枚举层过关，但调试协议层未启动"的位置。

每一层都有自己的验收标准：

| 层级 | 验收标准 | 典型工具 |
|---|---|---|
| USB/IP 协议层 | attach 成功，能交换 URB | usbip-win2 日志、ESProbe 串口 |
| USB 枚举层 | 描述符正确，驱动加载 | 设备管理器、USB Device Tree Viewer |
| USB 功能层 | bulk 传输可靠，无异常 unlink | USBLyzer、USBPcap |
| 调试协议层 | DAP 命令响应正确 | pyOCD -vvvvvv、OpenOCD -d3 |
| 应用层 | 能下载、能断点、能单步 | IDE、GDB |

ESProbe 当前卡在"USB 枚举层过关，但调试协议层未启动"的位置。这意味着最可能的战场在**功能层的 WinUSB pipe 就绪时机**和**USB/IP 层的 URB 时序匹配**之间。

---

## 结论与下一步

**当前结论**：

1. ESProbe 的 USB/IP Server 实现、USB 描述符、Microsoft OS 2.0 描述符在枚举层面是正确的——设备管理器能识别就是证据。
2. pyOCD 和 Keil 不识别，根因大概率不在"ESProbe 是不是 CMSIS-DAP"，而在"WinUSB pipe 是否已就绪"或"URB 时序是否满足 usbip-win2 的预期"。
3. 物理 DAPLink 初次连接也慢，说明 Windows 驱动安装是固有延迟；USB/IP 每次 attach 都相当于"首次插入"，这个延迟被放大了。

**下一步行动**：

1. **验证假设 A**：在 attach 后增加固定等待时间，测试 pyOCD/Keil 识别率是否有改善。
2. **验证假设 B**：在 Linux 上运行 `usbip attach` + pyOCD，交叉验证是固件问题还是 usbip-win2 兼容性问题。
3. **验证假设 C**：修复配置描述符的分包发送逻辑，确保 `data_length` 与实际 payload 严格一致。
4. **长期优化**：考虑在 ESProbe 固件中实现更智能的 URB 调度策略，或者探索更稳定的 USB/IP 客户端替代方案。

---

## 参考与工具

- **usbip-win2**: https://github.com/vadimgrn/usbip-win2
- **usbip-win**: https://github.com/cezanne/usbip-win
- **USB/IP 协议**: https://usbip.sourceforge.net/
- **pyOCD CMSIS-DAP 后端**: https://pyocd.io/docs/debug_probes.html
- **ESProbe 固件 USB/IP 实现**: `fw/main/usbip_server.c`, `fw/main/DAP_handle.c`
- **Windows USB 调试工具**: USB Device Tree Viewer, USBLyzer, USBPcap

---

## 附录：需要补充的手工截图清单

以下截图需要基于实际运行环境截取，无法通过 Mermaid 自动生成：

| 编号 | 截图内容 | 优先级 | 用途 |
|---|---|---|---|
| **占位图 1** | 左：设备管理器中 ESProbe 的 CMSIS-DAP 设备；右：pyOCD `pyocd list` 返回空列表 | ⭐⭐⭐ | 文章封面/引言对比，最直观的现象证据 |
| **占位图 2** | ESProbe 串口日志截图，用红框标出 `unlink` 密集区，与上方 EP0 正常枚举形成对比 | ⭐⭐⭐ | 核心证据，支撑假设 B |
| **可选图 3** | USB Device Tree Viewer 对比：DAPLink vs ESProbe 的 pipe 信息 | ⭐ | 验证假设 A（WinUSB 管道就绪） |
| **可选图 4** | USBLyzer/USBPcap 抓包：对比配置描述符读取的差异 | ⭐ | 验证假设 C（描述符分包） |

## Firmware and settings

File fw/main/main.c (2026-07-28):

/* ESProbe Wireless DAPLink Firmware
   Based on wireless-esp8266-dap, ported to ESP-IDF 5.5.x
*/
#include <string.h>
#include <stdint.h>
#include <sys/param.h>

#include "sdkconfig.h"
#include "main/tcp_server.h"
#include "main/uart_bridge.h"
#include "main/timer.h"
#include "main/wifi_configuration.h"
#include "main/wifi_handle.h"
#include "main/led_status.h"
#include "main/button_handle.h"
#include "main/web_server.h"
#include "main/access_control.h"
#include "main/dap_configuration.h"
#include "components/USBIP/usb_descriptor.h"

#include "freertos/FreeRTOS.h"
#include "freertos/task.h"
#include "freertos/event_groups.h"
#include "esp_system.h"
#include "esp_wifi.h"
#include "esp_log.h"
#include "nvs_flash.h"

#include "lwip/err.h"
#include "lwip/sockets.h"
#include "lwip/sys.h"
#include <lwip/netdb.h>

#include "mdns.h"

extern void DAP_Setup(void);
extern void DAP_Thread(void *argument);

TaskHandle_t kDAPTaskHandle = NULL;

static const char *MDNS_TAG = "server_common";

#if defined(CONFIG_IDF_TARGET_ESP32S3)
#define DAP_TASK_AFFINITY 1
#else
#define DAP_TASK_AFFINITY 0
#endif

void mdns_setup() {
    int ret;
    ret = mdns_init();
    if (ret != ESP_OK) {
        ESP_LOGW(MDNS_TAG, "mDNS initialize failed:%d", ret);
        return;
    }

    ret = mdns_hostname_set(MDNS_HOSTNAME);
    if (ret != ESP_OK) {
        ESP_LOGW(MDNS_TAG, "mDNS set hostname failed:%d", ret);
        return;
    }
    ESP_LOGI(MDNS_TAG, "mDNS hostname set to: [%s]", MDNS_HOSTNAME);

    ret = mdns_instance_name_set(MDNS_INSTANCE);
    if (ret != ESP_OK) {
        ESP_LOGW(MDNS_TAG, "mDNS set instance name failed:%d", ret);
        return;
    }
    ESP_LOGI(MDNS_TAG, "mDNS instance name set to: [%s]", MDNS_INSTANCE);

    // Advertise the CMSIS-DAP / USBIP service (_dap._tcp on port 3240) with
    // TXT metadata so discovery tools can display device details.
    mdns_txt_item_t dap_txt[] = {
        {"fw", ESPROBE_FW_VERSION},
        {"device", "ESProbe"},
        {"proto", "usbip+elaphurelink"},
        {"uart_port", "1234"},
    };
    ret = mdns_service_add("ESProbe DAP", "_dap", "_tcp", PORT,
                           dap_txt, sizeof(dap_txt) / sizeof(dap_txt[0]));
    if (ret != ESP_OK) {
        ESP_LOGW(MDNS_TAG, "mDNS add _dap service failed:%d", ret);
    }

    // Advertise the web config/OTA portal (_http._tcp on port 80).
    ret = mdns_service_add("ESProbe Web", "_http", "_tcp", 80, NULL, 0);
    if (ret != ESP_OK) {
        ESP_LOGW(MDNS_TAG, "mDNS add _http service failed:%d", ret);
    }
}

void app_main() {
    ESP_ERROR_CHECK(nvs_flash_init());

    // Load optional debug-port PIN before any server starts listening.
    access_control_init();

    // LED status indicator starts in BOOTING state.
    led_status_init();

    // Generate the USB serial number descriptor from the device MAC so that
    // multiple probes on the same network are distinguishable.
    usb_descriptor_set_serial_from_mac();

#if (USE_UART_BRIDGE == 1)
    uart_bridge_init();
#endif
    wifi_init();
    DAP_Setup();
    timer_init();

    // BOOT button: long-press = clear WiFi creds, short-press = target nRESET.
    button_handle_init();

#if (USE_MDNS == 1)
    mdns_setup();
#endif

#if (USE_WEB_SERVER == 1)
    // HTTP config portal + status + OTA (port 80), works in STA and AP mode.
    web_server_start();
#endif

    // BSD socket TCP server for USBIP
    xTaskCreatePinnedToCore(tcp_server_task, "tcp_server", 8192, NULL, 14, NULL,
                            DAP_TASK_AFFINITY);

    // DAP handle task
    xTaskCreatePinnedToCore(DAP_Thread, "DAP_Task", 8192, NULL, 10, &kDAPTaskHandle,
                            DAP_TASK_AFFINITY);

#if defined CONFIG_IDF_TARGET_ESP8266
    #define UART_BRIDGE_TASK_STACK_SIZE 1024
#else
    #define UART_BRIDGE_TASK_STACK_SIZE 2048
#endif

#if (USE_UART_BRIDGE == 1)
    xTaskCreate(uart_bridge_task, "uart_server", UART_BRIDGE_TASK_STACK_SIZE, NULL, 2, NULL);
#endif
}

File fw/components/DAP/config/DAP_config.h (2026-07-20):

/*
 * Copyright (c) 2013-2017 ARM Limited. All rights reserved.
 *
 * SPDX-License-Identifier: Apache-2.0
 *
 * Licensed under the Apache License, Version 2.0 (the License); you may
 * not use this file except in compliance with the License.
 * You may obtain a copy of the License at
 *
 * www.apache.org/licenses/LICENSE-2.0
 *
 * Unless required by applicable law or agreed to in writing, software
 * distributed under the License is distributed on an AS IS BASIS, WITHOUT
 * WARRANTIES OR CONDITIONS OF ANY KIND, either express or implied.
 * See the License for the specific language governing permissions and
 * limitations under the License.
 *
 * ----------------------------------------------------------------------
 *
 * $Date:        16. June 2021
 * $Revision:    V2.1.0
 *
 * Project:      CMSIS-DAP Configuration
 * Title:        DAP_config.h CMSIS-DAP Configuration File (Template)
 *
 *---------------------------------------------------------------------------*/

/**
 * @file DAP_config.h
 * @author windowsair
 * @brief Adaptation of GPIO and SPI pin
 * @change: 2021-2-10 Support GPIO and SPI
 *          2021-2-18 Try to support SWO
 *          2024-1-28 Update to CMSIS-DAP v2.1.0
 * @version 0.3
 * @date 2024-1-28
 *
 * @copyright Copyright (c) 2021-2024
 *
 */


#ifndef __DAP_CONFIG_H__
#define __DAP_CONFIG_H__

#include <stdint.h>
#include <string.h>

#include "main/dap_configuration.h"
#include "main/wifi_configuration.h"
#include "main/timer.h"

#include "components/DAP/include/cmsis_compiler.h"
#include "components/DAP/include/gpio_op.h"
#include "components/DAP/include/spi_switch.h"


#ifdef CONFIG_IDF_TARGET_ESP8266
  #include "gpio.h"
  #include "esp8266/include/esp8266/gpio_struct.h"
  #include "esp8266/pin_mux_register.h"
#elif defined CONFIG_IDF_TARGET_ESP32
#elif defined CONFIG_IDF_TARGET_ESP32C3
#elif defined CONFIG_IDF_TARGET_ESP32S3
#else
  #error unknown hardware
#endif



//**************************************************************************************************
/**
\defgroup DAP_Config_Debug_gr CMSIS-DAP Debug Unit Information
\ingroup DAP_ConfigIO_gr
@{
Provides definitions about the hardware and configuration of the Debug Unit.

This information includes:
 - Definition of Cortex-M processor parameters used in CMSIS-DAP Debug Unit.
 - Debug Unit Identification strings (Vendor, Product, Serial Number).
 - Debug Unit communication packet size.
 - Debug Access Port supported modes and settings (JTAG/SWD and SWO).
 - Optional information about a connected Target Device (for Evaluation Boards).
*/

//#ifdef _RTE_
//#include "RTE_Components.h"
//#include CMSIS_device_header
//#else
//#include "device.h"                             // Debug Unit Cortex-M Processor Header File
//#endif

/// Processor Clock of the Cortex-M MCU used in the Debug Unit.
/// This value is used to calculate the SWD/JTAG clock speed.
#ifdef CONFIG_IDF_TARGET_ESP8266
  #define CPU_CLOCK 160000000 ///< Specifies the CPU Clock in Hz.
  // <<<<<<<<<<<<<<<<<<<<<<<<<<<<<160MHz
#elif defined CONFIG_IDF_TARGET_ESP32
  #define CPU_CLOCK 240000000
  // <<<<<<<<<<<<<<<<<<<<<<<<<<<<<240MHz
#elif defined CONFIG_IDF_TARGET_ESP32C3
  #define CPU_CLOCK 160000000
  // <<<<<<<<<<<<<<<<<<<<<<<<<<<<<160MHz
#elif defined CONFIG_IDF_TARGET_ESP32S3
  #define CPU_CLOCK 240000000
#endif



//#define MAX_USER_CLOCK 16000000 ///< Specifies the max Debug Clock in Hz.

/// Number of processor cycles for I/O Port write operations.
/// This value is used to calculate the SWD/JTAG clock speed that is generated with I/O
/// Port write operations in the Debug Unit by a Cortex-M MCU. Most Cortex-M processors
/// require 2 processor cycles for a I/O Port Write operation.  If the Debug Unit uses
/// a Cortex-M0+ processor with high-speed peripheral I/O only 1 processor cycle might be
/// required.
#define IO_PORT_WRITE_CYCLES 2U ///< I/O Cycles: 2=default, 1=Cortex-M0+ fast I/0.

/// Indicate that Serial Wire Debug (SWD) communication mode is available at the Debug Access Port.
/// This information is returned by the command \ref DAP_Info as part of <b>Capabilities</b>.
#define DAP_SWD 1 ///< SWD Mode:  1 = available, 0 = not available.

/// Indicate that JTAG communication mode is available at the Debug Port.
/// This information is returned by the command \ref DAP_Info as part of <b>Capabilities</b>.
#define DAP_JTAG 0 ///< JTAG Mode: 1 = available, 0 = not available.

/// Configure maximum number of JTAG devices on the scan chain connected to the Debug Access Port.
/// This setting impacts the RAM requirements of the Debug Unit. Valid range is 1 .. 255.
#define DAP_JTAG_DEV_CNT 8U ///< Maximum number of JTAG devices on scan chain.

/// Default communication mode on the Debug Access Port.
/// Used for the command \ref DAP_Connect when Port Default mode is selected.
#define DAP_DEFAULT_PORT 1U ///< Default JTAG/SWJ Port Mode: 1 = SWD, 2 = JTAG.
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

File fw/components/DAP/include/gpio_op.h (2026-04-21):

/**
 * @file gpio_op.h
 * @author windowsair
 * @brief esp GPIO operation
 * @version 0.1
 * @date 2021-03-03
 *
 * @copyright Copyright (c) 2021
 *
 */

#ifndef __GPIO_OP_H__
#define __GPIO_OP_H__

#include "sdkconfig.h"
#include "components/DAP/include/cmsis_compiler.h"
#include "components/DAP/include/gpio_common.h"

#if defined(CONFIG_IDF_TARGET_ESP32S3) || defined(CONFIG_IDF_TARGET_ESP32C3)
#include "hal/cpu_ll.h"
#endif

#ifdef CONFIG_IDF_TARGET_ESP8266
__STATIC_INLINE __UNUSED void GPIO_FUNCTION_SET(int io_num)
{
  gpio_pin_reg_t pin_reg;

  pin_reg.val = READ_PERI_REG(GPIO_PIN_REG(io_num));

  // It should be noted that GPIO0, 2, 4, and 5 need to set the func register to 0,
  // and the other GPIO needs to be set to 3 so that IO can be GPIO function.
  if ((0x1 << io_num) & (GPIO_Pin_0 | GPIO_Pin_2 | GPIO_Pin_4 | GPIO_Pin_5)) {
      pin_reg.rtc_pin.func_low_bit = 0;
      pin_reg.rtc_pin.func_high_bit = 0;
  } else {
      pin_reg.func_low_bit = 3;
      pin_reg.func_high_bit = 0;
  }

  WRITE_PERI_REG(GPIO_PIN_REG(io_num), pin_reg.val);
}
#elif defined CONFIG_IDF_TARGET_ESP32
__STATIC_INLINE __UNUSED void GPIO_FUNCTION_SET(int io_num)
{
    // function number 2 is GPIO_FUNC for each pin
    // Note that the index starts at 0, so we are using function 3.
    PIN_FUNC_SELECT(GPIO_PIN_MUX_REG[io_num], PIN_FUNC_GPIO);
}
#elif defined CONFIG_IDF_TARGET_ESP32C3
__STATIC_INLINE __UNUSED void GPIO_FUNCTION_SET(int io_num)
{
  // Disable USB Serial JTAG if pins 18 or pins 19 needs to select an IOMUX function
  if (io_num == 18 || io_num == 19) {
      CLEAR_PERI_REG_MASK(USB_SERIAL_JTAG_CONF0_REG, USB_SERIAL_JTAG_USB_PAD_ENABLE);
  }
  PIN_FUNC_SELECT(GPIO_PIN_MUX_REG[io_num], PIN_FUNC_GPIO);
}
#elif defined CONFIG_IDF_TARGET_ESP32S3
__STATIC_INLINE __UNUSED void GPIO_FUNCTION_SET(int io_num)
{
  gpio_ll_iomux_func_sel(GPIO_PIN_MUX_REG[io_num], PIN_FUNC_GPIO);
}
#endif


#ifdef CONFIG_IDF_TARGET_ESP8266
__STATIC_INLINE __UNUSED void GPIO_SET_DIRECTION_NORMAL_OUT(int io_num)
{
  GPIO.enable_w1ts |= (0x1 << io_num);
  // PP out
  GPIO.pin[io_num].driver = 0;
}
#elif defined CONFIG_IDF_TARGET_ESP32
__STATIC_INLINE __UNUSED void GPIO_SET_DIRECTION_NORMAL_OUT(int io_num)
{
    GPIO.enable_w1ts = (0x1 << io_num);
    // PP out
    GPIO.pin[io_num].pad_driver = 0;
}
#elif defined CONFIG_IDF_TARGET_ESP32C3
__STATIC_INLINE __UNUSED void GPIO_SET_DIRECTION_NORMAL_OUT(int io_num)
{
    gpio_ll_output_enable(&GPIO, io_num);
    // PP out
    gpio_ll_od_disable(&GPIO, io_num);
}
#elif defined CONFIG_IDF_TARGET_ESP32S3
__STATIC_INLINE __UNUSED void GPIO_SET_DIRECTION_NORMAL_OUT(int io_num)
{
    gpio_ll_output_enable(&GPIO, io_num);
    // PP out
    gpio_ll_od_disable(&GPIO, io_num);
}
#endif


#if defined CONFIG_IDF_TARGET_ESP8266 || defined CONFIG_IDF_TARGET_ESP32
__STATIC_INLINE __UNUSED void GPIO_SET_LEVEL_HIGH(int io_num)
{
  GPIO.out_w1ts |= (0x1 << io_num);
}
//FIXME: esp32
__STATIC_INLINE __UNUSED void GPIO_SET_LEVEL_LOW(int io_num)
{
  GPIO.out_w1tc |= (0x1 << io_num);
}
#elif defined CONFIG_IDF_TARGET_ESP32C3 || defined CONFIG_IDF_TARGET_ESP32S3
__STATIC_INLINE __UNUSED void GPIO_SET_LEVEL_HIGH(int io_num)
{
  gpio_ll_set_level(&GPIO, io_num, 1);
}
__STATIC_INLINE __UNUSED void GPIO_SET_LEVEL_LOW(int io_num)
{
  gpio_ll_set_level(&GPIO, io_num, 0);
}
#endif


#if defined CONFIG_IDF_TARGET_ESP8266 || defined CONFIG_IDF_TARGET_ESP32
__STATIC_INLINE __UNUSED int GPIO_GET_LEVEL(int io_num)
{
  return ((GPIO.in >> io_num) & 0x1) ? 1 : 0;
}
#elif defined CONFIG_IDF_TARGET_ESP32C3 || defined CONFIG_IDF_TARGET_ESP32S3
__STATIC_INLINE __UNUSED int GPIO_GET_LEVEL(int io_num)
{
  return gpio_ll_get_level(&GPIO, io_num);
}
#endif

#if defined CONFIG_IDF_TARGET_ESP32 || defined CONFIG_IDF_TARGET_ESP32C3
__STATIC_INLINE __UNUSED void GPIO_PULL_UP_ONLY_SET(int io_num)
{
  // disable pull down
  REG_CLR_BIT(GPIO_PIN_MUX_REG[io_num], FUN_PD);
  // enable pull up
  REG_SET_BIT(GPIO_PIN_MUX_REG[io_num], FUN_PU);
}
#elif defined CONFIG_IDF_TARGET_ESP32S3
__STATIC_INLINE __UNUSED void GPIO_PULL_UP_ONLY_SET(int io_num)
{
  // disable pull down
  gpio_ll_pulldown_dis(&GPIO, io_num);
  // enable pull up
  gpio_ll_pullup_en(&GPIO, io_num);
}
#elif defined CONFIG_IDF_TARGET_ESP8266
__STATIC_INLINE __UNUSED void GPIO_PULL_UP_ONLY_SET(int io_num)
{
  gpio_pin_reg_t pin_reg;

  pin_reg.val = READ_PERI_REG(GPIO_PIN_REG(io_num));
  pin_reg.pullup = 1;
  WRITE_PERI_REG(GPIO_PIN_REG(io_num), pin_reg.val);
}
#endif
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

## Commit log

2026-03-31 PCB布局布线
2026-04-01 完成PCB布局布线，投板
2026-04-02 增加3d打印外壳
    [ESProbe上.stl, ESProbe下.stl]
2026-04-09 增加电源路径管理
2026-04-21 Add UART bridge and USBIP server functionality
    - Implemented uart_bridge.c and uart_bridge.h for UART TCP bridging.
    - Added usbip_server.c and usbip_server.h to handle USB over IP communication.
    - Created wifi_configuration.h and wifi_handle.c for Wi-Fi management.
    - Introduced configuration options in sdkconfig.defaults for ESP32-C3.
    - Added hardware design files and README for ESProbe hardware specifications.
    - Included necessary event handling for Wi-Fi connection and disconnection.
    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
2026-04-23 fix(esp32c3): ESP-IDF 5.5 GPIO/SPI compatibility fixes
    [DAP_config.h, spi_switch.c]
2026-04-23 feat(tcp-uart): Add TCP-to-UART bridge test script
2026-04-27 修改上壳，增加标签位凹槽
    [ESProbe上.stl]
2026-07-20 feat(fw): add LED status, BOOT button, NVS WiFi, AP fallback and DAP timestamp
    Phase 1 quick-win features:
    - LED status patterns (booting/connecting/connected/AP/error) via led_status.c
    - BOOT button: long-press clears NVS WiFi creds, short-press pulses nRESET
    - NVS-backed WiFi credential storage with Kconfig fallback
    - WiFi AP fallback mode (ESProbe-XXXX) after N STA retries
    - DAP timestamp fix: esp_timer_get_time() + TIMESTAMP_CLOCK 1MHz
    - Firmware version string via DAP_GetProductFirmwareVersionString
    [DAP_config.h, button_handle.c, led_status.c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]
2026-07-20 feat(fw): add web config portal, OTA update, mDNS metadata and MAC-based USB serial
    Phase 2 features:
    - Web config portal (port 80): GET / form saves WiFi creds to NVS + reboot
    - HTTP status endpoint GET /status (JSON: fw/mode/ip/rssi/uptime/partition)
    - Wireless OTA via POST /ota using esp_ota_ops + two_ota partition table
    - mDNS service metadata: _dap._tcp:3240 + _http._tcp:80 with TXT records
    - USB serial number descriptor generated from device MAC (distinguish probes)
    - wifi_is_ap_mode() accessor; build verified on ESP-IDF 5.5.x
    NOTE: partition table changed singleapp -> two_ota; existing devices need a
    one-time full UART flash before OTA works, and NVS is reset.
    [main.c, web_server.c, wifi_configuration.h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]
2026-07-27 chore(agents): 指令资产入库并同步过期事实
    - fw/AGENTS.md 入库（移除 fw/.gitignore 忽略规则），同步 IDF v5.5.4、模块清单、OTA 现状，并声明与 Skill 的 canonical 分工
    - .agents/skills/esprobe-dap-firmware 源目录入库，架构事实按 CMakeLists 真值修正
    - 新增 fw/scripts/verify_build.ps1 构建验证门（支持 IDF_TOOLS_PATH 覆盖）
    - 根 .gitignore：忽略 videos/、.qoder/、*.skill 打包件
2026-07-27 docs: 微信公众号文章与配图入库
    ESProbe 系列文章（blink/技术原理/Web OTA+mDNS/usbip-win/elaphureLink 等）及 assets 配图
2026-07-28 feat(fw): PIN access control and web serial terminal
    - access_control: NVS-stored PIN, per-IP unlock sessions via web portal; gates TCP 3240 and UART bridge 1234; no PIN = fully open (backward compatible)
    - web_server: Security card (/unlock, /pin), /terminal page, /ws/uart WebSocket-UART bridge with shared-claim against TCP bridge
    - elaphureLink: extract pure el_handshake_validate/el_be32 helpers (host-testable)
    - sdkconfig.defaults: enable CONFIG_HTTPD_WS_SUPPORT
    - docs: correct stale timer-stub description (esp_timer implementation already present)
    [main.c, uart_bridge.c]
2026-07-28 ci: GitHub Actions firmware build and host protocol tests
    - host-tests job: gcc-compiled protocol unit tests (elaphureLink handshake validation, USBIP header ABI), 24 checks
    - firmware job: esp-idf-ci-action v5.5.4 esp32c3 build with artifact upload

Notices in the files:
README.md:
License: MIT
